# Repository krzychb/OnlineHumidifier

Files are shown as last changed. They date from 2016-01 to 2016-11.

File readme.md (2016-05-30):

# Online Humidifier

This repository provides step by step guide how to automatically control humidity in your home.

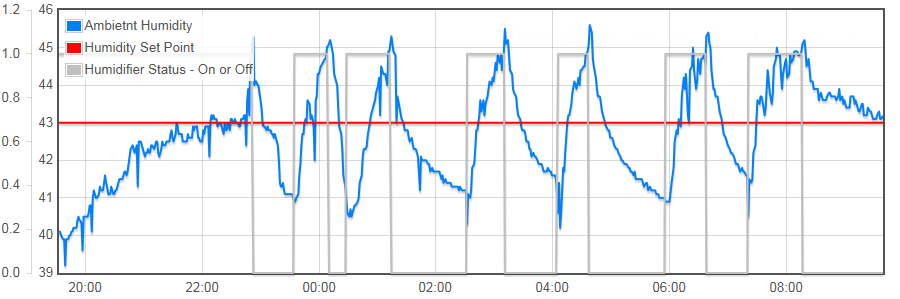
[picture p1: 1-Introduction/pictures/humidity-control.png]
Humidity control in operation


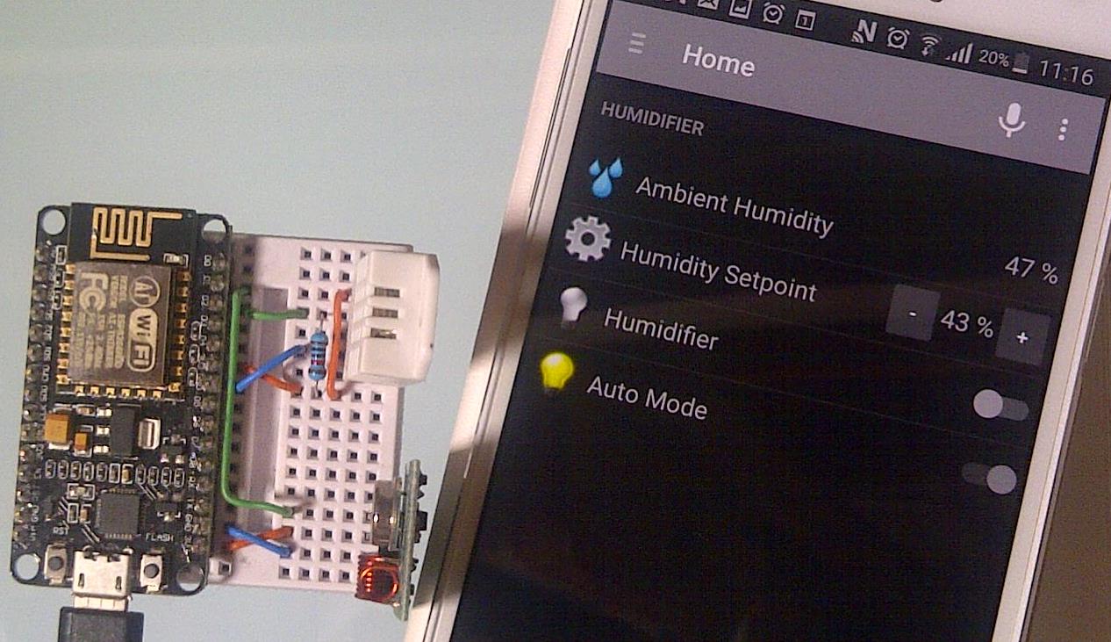
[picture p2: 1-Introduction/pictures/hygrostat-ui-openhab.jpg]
Hygrostat and User interface in openAHB


It is fun to build, consists of easy to get components and costs just $50.

## What You Need

There are only couple of cheap and easy to get components to make your project running

* Humidifier - $25
* ESP8266 board - $8
* Humidity sensor - $5
* RC Socket - $5
* RF Transmitter - $1 
* Breadboard - $5
* Cables - $1
* PC - $0 - you likely have one already as you are reading this web page :smile:

For more details please refer to [Components](2-Components) section.

## Step by Step Tutorial

Depending on your experience, to make implementation easier, this project is broken down into the following steps:

* [**Introduction**](1-Introduction) - check it to learn more about this project and how we are going to implements it.

* [**Components**](2-Components) - describes in detail components you need and what you should look at when buying them.

* [**Setup**](3-Setup) - how to configure Arduino IDE for ESP8266 and compile first sketch

* [**Measure**](4-Measure) - details how to measure humidity with ESP8266 and DHT22 sensor.

* [**Show**](5-Show) - go on line and show humidity measurements in web browser.

* [**Chart**](6-Chart) - how to push data to the cloud and display nice charts with measurements.

* [**Control**](7-Control) - switch on and off wireless RF 433MHz socket using ESP8266 and RF transmitter.

* [**Automate**](8-Automate) - with all preparation done in prevoius steps now we are ready to put our humidity control system together and switch it into auto mode!

* [**Maintain**](9-Maintain) - how to make code uploads easier and quicker with OTA (Over The Air) updates.

#### Appendixes

* [**MQTT**](A1-MQTT) - communicate with other devices using MQTT protocol.

* [**openHAB**](A2-openHAB) - control humidifier from your mobile device using [openHAB](http://www.openhab.org/). 

* [**HTTP**](A3-HTTP) - interface ESP8266 and openHAB using HTTP binding. Is it a viable alternative to MQTT binding?

* [**Persistence**](A4-Persistence) - save sensor values on your local PC instead in the cloud using *persistence* functionality provided by openHAB.

**Note:** If you do not have much experience with Arduino IDE programming and ESP8266, please don't skip ahead in sections of this repository! New concepts are introduced step by step and you may miss something that will be important later. As result you may get stuck trying to make the sketch or other applications work.

## Contribute

Feel free to contribute to the project in any way you like! 

If you find any issues with code or descriptions please report them using *Issues* tab above. 

If you like to discuss it please use [this thread](http://www.esp8266.com/viewtopic.php?p=37446#p37446) on ESP8266 Community Forum. 

## Author

krzychb

## Donations

Invite me to freshly squeezed orange juice.

## Credits

Software for this project has been prepared thanks to great work of the following teams and individuals:
* Arduino team that develops and maintains versatile [Arduino IDE](https://www.arduino.cc/)
* esp8266/Arduino team lead by [Ivan Grokhotkov](https://twitter.com/i_grr) that brought to us great [ESP8266 core for Arduino](https://github.com/esp8266/Arduino)
* [adafruit](https://www.adafruit.com/) providing [DHT sensor library](https://github.com/adafruit/DHT-sensor-library) that is only one of numerous examples of open software adafruit contributed to community
* [Randy Simons](http://randysimons.nl/88,over-mij/) who prepared [433MHz libraries for Arduino](http://randysimons.nl/26-433mhz-libraries-for-arduino)
* [Friends-of-Fritzing](http://friends.fritzing.org/) foundation - developer of widely used and really nice and friendly [Fritzing](http://fritzing.org/home/) 
* [Kamil Baczkowicz]( https://github.com/kamilfb) - the author of versatile and really user friendly [mqtt-spy]( http://kamilfb.github.io/mqtt-spy/), an application that provides tremendous help when testing MQTT communication and debugging MQTT messages
* [Imroy](https://github.com/Imroy) - developer of [PubSubClient](https://github.com/Imroy/pubsubclient), a MQTT library fork of https://github.com/knolleary/pubsubclient

## License

[GNU LESSER GENERAL PUBLIC LICENSE - Version 2.1, February 1999](LICENSE)

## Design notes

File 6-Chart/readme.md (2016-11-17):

# Chart

## Table of Contents

* [Introduction](#introduction)
* [Emoncms](#emoncms)
* [Setup](#setup)
* [Push](#push)
* [Visualize](#visualize)
* [Save](#save)
* [Chart](#chart)
* [Next Steps](#next-steps)

## Introduction

I think that development of applications for ESP8266 has been made really easy to everybody. This is thanks to [ESP8266 core for Arduino](https://github.com/esp8266/Arduino) developed by [Ivan Grokhotkov](https://twitter.com/i_grr) and [esp8266/Arduino](https://github.com/esp8266/Arduino/graphs/contributors) team. In [previous section](../5-Show) I have shown how easy it is to present measurements online with just couple of simple modifications to existing example sketch.

In this section I would like to make another step - push data to the cloud and present them online on a chart. 

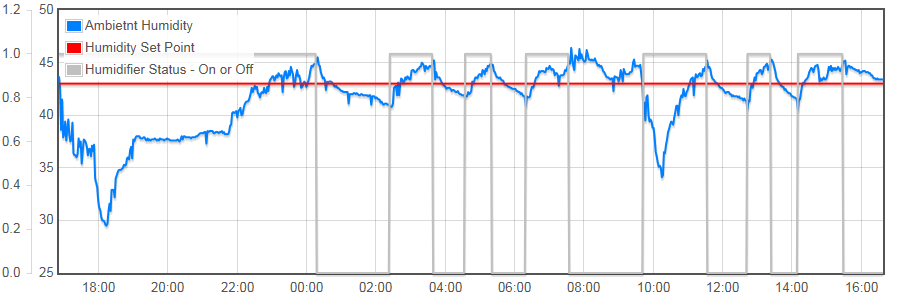
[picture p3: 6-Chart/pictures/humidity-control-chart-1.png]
A sample humidity control chart


## Emoncms

There are several cloud services that you can use for such purpose. I am pretty familiar with [ThingSpeak](https://thingspeak.com/) and [Emoncms](http://emoncms.org/) and will refer to them.

For this particular project I propose to use [Emoncms](http://emoncms.org/). I found it easier to configure a chart to show multiple values, that you can quickly browse or zoom for the period you want. 

After putting our automatic humidity control into operation we would like to be able to analyse its performance. We will do it by checking relationship between humidity set point, actual humidity value and on/off status of humidifier. It is easier to do it on a single chart rather than on three separate charts. 

On the other hand I can recommend [ThingSpeak](https://thingspeak.com/) if you need flexibility of extra data processing before displaying. ThinkSpeeak provides MATLAB for that and imagine what fancy things you can do with it! After processing you can then display the data using huge [charts or plots](https://www.mathworks.com/products/matlab/plot-gallery.html?refresh=true) gallery.

## Setup

Go ahead, open http://emoncms.org/ and register. All you need to provide is login, e-mail and password. Once registered, you will get free access to storage space for your data as well as dashboards to present them online.

To learn how to send data to Emoncms, login into it, go to *Setup > Inputs* and open [Input API Help](http://emoncms.org/input/api) link. Under chapter *Available JSON commands* you will be able see a link like: ``` http://emoncms.org/input/post.json?json={power:200}&apikey=9a3e3c9cf65c70a597097b065dcb24e3 ```. This is so called [JSON](https://en.wikipedia.org/wiki/JSON) command used to send data to Emoncms cloud. It consists of three parts:

1.	``` http://emoncms.org/input/post.json?json= ``` : an url to server that processes JSON,
2.	``` {power:200} ``` : data to be sent as a name:value pair (you can add more pairs separated by comma),
3.	``` apikey=9a3e3c9cf65c70a597097b065dcb24e3 ``` : unique identifier of your space on Emoncms.

You will find your API keys at the top of API Hep page. To post data use “Read & Write” key.

**Note:** Formal description of JSON is provided in [RFC 7159](https://tools.ietf.org/html/rfc7159) standard. According to this standard, the name (as a string) should begin and end with quotation marks. This is not the case in example above, as `power` is not enclosed in quotation marks. Keep in mind, that even if it works for Emoncms, it may not work elsewhere. 

## Push

Now we need to instruct ESP to periodically measure humidity and open similar JSON link but containing something like ``` {Humidity:43.5} ```, where ``` Humidity ``` is the name of value we are sending and ``` 43.5 ``` is the value itself. 

Let us program the above operations as functions so it is easier to follow what our code is doing. Functions will be called in a loop every 20 seconds, or so that we can quickly see results. We can increase this period once testing is complete – afterwards is not really required to check humidity level in a room every 20 seconds.

```cpp
loop()
{
  measureHumidity();
  sendDataToEmoncms();

   delay(20000);  // wait 20 seconds
}
```

To prepare the function that will measure humidity, open [DHTtester.ino sketch we have discussed before](../4-Measure#software-setup), copy code and modify it, so humidity is measured and stored in a global variable ``` humidity ```. What I did looks like follows:

```cpp
void measureHumidity(void)
{
  humidity = dht.readHumidity();
  if (isnan(humidity))
  {
    Serial.println("Failed to read from DHT sensor!");
    return;
  }
  Serial.print("Humidity: ");
  Serial.println(humidity);
}
```

You will also need a function to send JSON command to Emoncms and it looks like below.

```cpp
void sendDataToEmoncms(void)
{
  if (client.connect(emoncmsServer, 80))
  {
    String getJSON = "";
    getJSON += "GET http://" + (String) emoncmsServer;
    getJSON += "/input/post.json?json={Humidity:" + (String) humidity + "}";
    getJSON += "&apikey=" + apiKeyEmoncms + "\n";
    getJSON += "Connection: close\n\n";
    client.print(getJSON);
    // display response from Emoncms
    while (client.available())
    {
      Serial.write(client.read());
    }
    Serial.println("Data sent to Emoncms");
  }
  else
  {
    Serial.println("Connection to Emoncms failed");
  }
  client.stop();
}
```

This code opens a new client connection to Emoncms server, sends JSON command, shows received response and finally closes the connection. 

To make this code work we need to declare global variable ``` humidity```.

```cpp
float humidity;
```

We should also declare a string ```emoncmsServer``` containing domain name of Emoncms, another string with the API key (enter your own!) and declare ``` client ``` object. 

```cpp
// Domain name of emoncms server - "emoncms.org"
// If unable to connect with domant name, use IP adress instead - "80.243.190.58"
const char* emoncmsServer = "emoncms.org";
// enter your Write & Write API Key below 
String apiKeyEmoncms = "9a3e3c9cf65c70a597097b065dcb24e3";
WiFiClient client;
```

A copy of complete sketch is saved as [OnlineHumidifier-Graph](OnlineHumidifier-Graph/) and consists of three files that contain individual parts of code – initialization, ``` setup() ``` & ``` loop() ```, humidity measurement and sending data to Emoncms. Such code “modularity” will make it easier to follow and understand growing code as we will be adding some more new functionality.

## Visualize

Once you upload and run this sketch, go to [Inputs](http://emoncms.org/input/view) where you should be able to see humidity value periodically send on Emoncms.

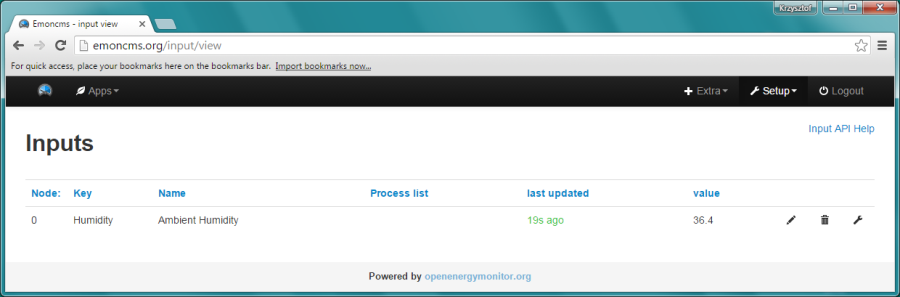
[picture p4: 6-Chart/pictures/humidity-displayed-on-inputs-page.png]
Humidity value displayed on Inputs page


In case of issues check on Serial Monitor what messages are shown – especially what is the reply from Emoncms after JSON command is sent. If command is properly formatted and includes a valid API key, the reply will be just ``` ok ```. Otherwise you should see specific error codes. A handy way to you can troubleshoot is to prepare JSON command in text editor, paste it to a web browser and check what reply is returned. 

If JSON string is correctly formatted, then you should see response as below:

JSON string phrased correctly

In case of errors, for instance if API key is incorrect, you should see specific message:

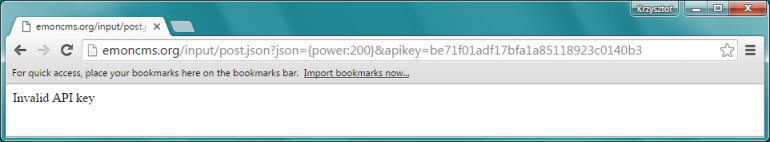
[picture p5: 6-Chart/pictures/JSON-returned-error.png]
JSON string returned an error


Before going to the next step you need make this sketch working, so humidity is properly updated under [Inputs](http://emoncms.org/input/view) every 20 seconds, or according to other specific delay defined in the ``` loop()```. [Minimum interval you can post data to Emoncms is 10s](http://emoncms.org/site/usage) so put a brake on your ESP8266 module!

## Save

In next steps we need to instruct Emoncms to save all the values we send. What you see under [Inputs](http://emoncms.org/input/view) is just last received value. Track record of inputs in maintained under [Feeds](http://emoncms.org/feed/list). To add the Humidity input Feeds, click the wrench symbol shown on right.

Then select Feed engine and press *Add* button

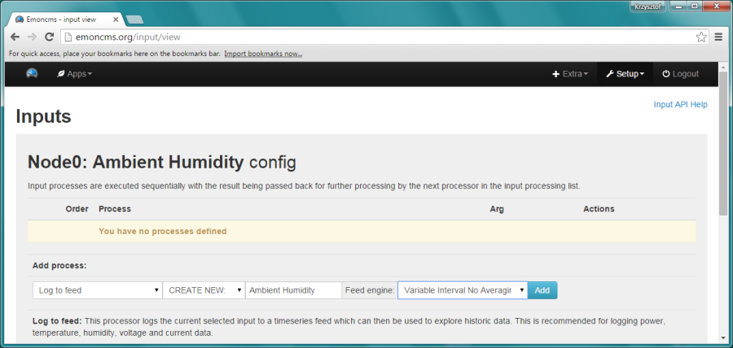
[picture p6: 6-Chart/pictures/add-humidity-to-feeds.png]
Adding Humidity input to Feeds


Congratulations! Now all humidity values you send are stored on Emoncms.

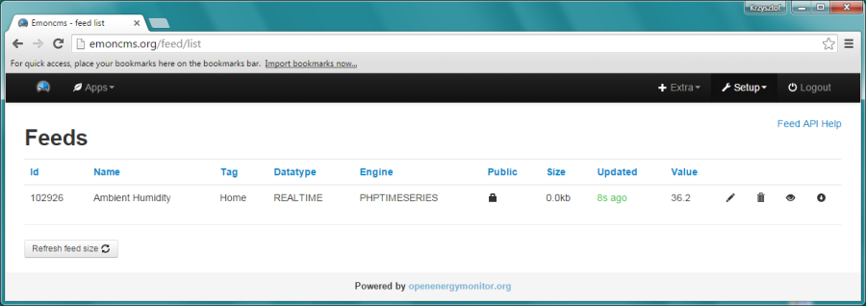
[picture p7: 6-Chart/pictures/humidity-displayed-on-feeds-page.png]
Humidity value displayed on Feeds page


## Chart

We are almost there! We can now use humidity feed to show in on a chart. Go to [Dashboards](http://emoncms.org/dashboard/list), click *New* and then click edit symbol on newly created dashboard. 

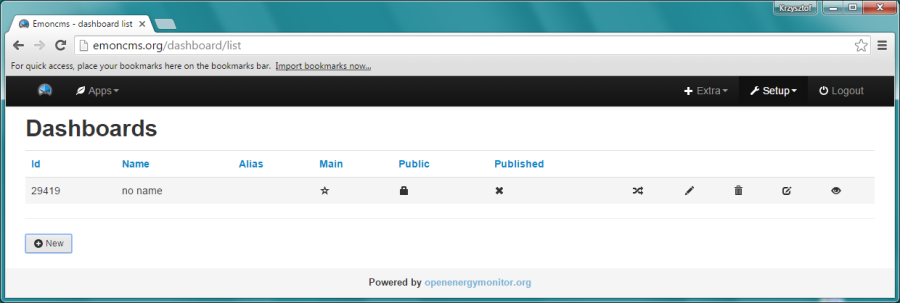
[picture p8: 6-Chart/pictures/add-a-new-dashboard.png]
Add a new dashboard


Open *Visualisation* drop down list, select *rawdata*, click and place a rectangle representing the new chart. After that click *Configure* and select recently created feed with humidity values. After saving changes you should be able to see the chart with humidity measurement updated online with values sent from your ESP board.

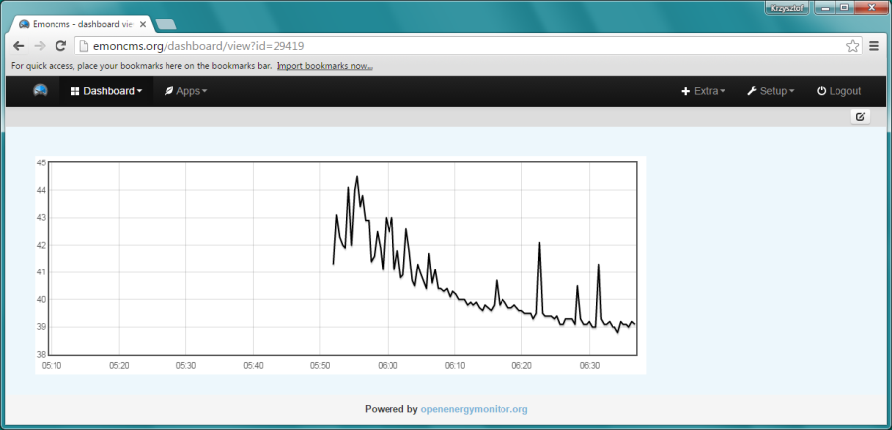
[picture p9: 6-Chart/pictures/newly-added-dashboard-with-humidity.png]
Newly added dashboard with humidity chart


Go ahead and experiment with various visualizations, widgets, containers and text. For more details how to use them, refer to https://github.com/emoncms/emoncms.

## Next Steps

Once you get comfortable with your new sketch and Emoncms, make some improvements by sending more than just a single name:value pair at a time. For example an instruction like ```{Humidity:43.5, Temperature:22.3}```  will send to Emoncms two variables, first named ``` Humidity ``` with value  of ``` 43.5 ``` and second named ``` Temperature ``` with value of ``` 22.3 ```. Then practice putting both variables on a single chart. To do so use *multigraph* type chart from *Visualizations*.

This concludes my instructions how to send data to Emoncms and show them on a chart. In next section [Control](../7-Control) I will show you how to switch humidifier on and off remotely. With this functionality in place we will be just a step ahead from getting our humidifier automatically controlling humidity! 

Stick with me – this will be fun!

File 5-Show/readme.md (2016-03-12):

# Show

## Table of Contents

* [Introduction](#introduction)
* [What You Need](#what-you-need)
* [Setup Web Server](#setup-web-server)
* [Test It](#test-it)
* [Next Step](#next-step)

## Introduction

In [previous section](../4-Measure)  I have shown how to use an inexpensive digital humidity sensor DHT22 with ESP8266 to measure relative humidity. We have been displaying humidity values in Serial Monitor of Arduino IDE.

Now it is time to do next step and use ESP’s Wi-Fi functionality and show humidity values in a web browser. I am really excited to show you that, since it provides freedom to get our measurements online and shown them to the whole world!

Such functionality is also fairly easy to complete. There is an example sketch available in Arduino IDE that demonstrates how to set up a simple web server on an ESP. We will use it to serve a web page with humidity measurement that we or anybody else can open in a web browser :sunglasses:

Let's get started!

## What You Need

To implement this part of project you will need the following:

* All the hardware used in [previous section](../4-Measure) to program ESP and to measure humidity:
  * PC with [esp8266/Arduino](https://github.com/esp8266/Arduino) IDE
  * ESP module
  * DHT22 sensor on breadboard
* Wi-Fi access for PC and ESP module to the same network

## Setup Web Server

Start by going to File > Examples > ESP8266WebServer and opening HelloServer.ino sketch.

Update station ID and password in sketch so your ESP can access Wi-Fi network and upload it.

Once upload is complete press Ctrl+Shift+ M to open Serial Monitor. What you are looking for is a message like on screenshot below, that ESP module has connected to Wi-Fi network and IP address of web server running on ESP.

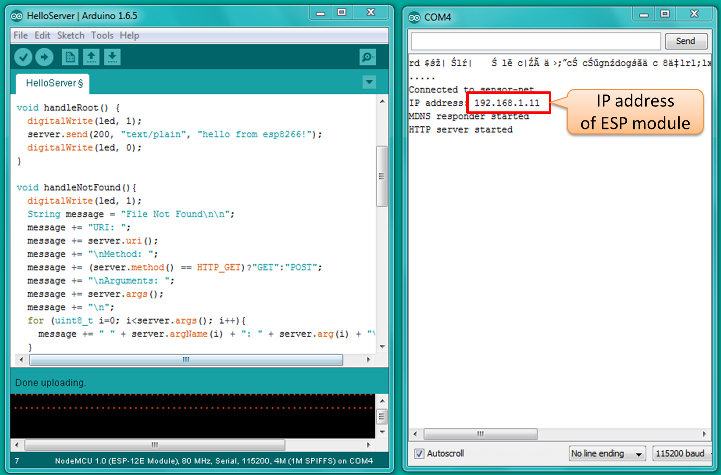
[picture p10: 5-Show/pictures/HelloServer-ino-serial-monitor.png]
IP address of ESP module connected to Wi-Fi network


Go ahead, open web browser and type IP address provided on Serial Monitor. If you are connected to the same network you should be able to see “hello from esp8266!” message from ESP module. 

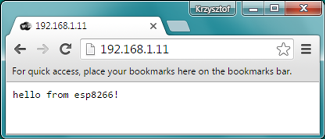
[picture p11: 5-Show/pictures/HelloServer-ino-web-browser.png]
"hello from esp8266!” in web browser


Now go to the sketch and locate function that sends out the “hello” message. What we would like to do, is to change this message, so it contains current humidity value. We will reuse code we tested so far. First please open File > Examples > ESP8266WebServer > HelloServer.ino sketch and save it as OnlineHumidifier-Show.ino. Then open File > Examples > DHT sensor library > DHTtester.ino sketch and copy from it the code we need to print out humidity value. Please see below pieces of code we need.

Declaration section
```cpp
#include "DHT.h"
DHT dht(D2, DHT22);
```

Updated ``` handleRoot() ``` function

```cpp
void handleRoot() {
  digitalWrite(led, LOW);
  String message = "hello from esp8266!\n";
  message += "Humidity = ";
  message += (String) dht.readHumidity();
  message += "%\n\n";
  server.send(200, "text/plain", message);
  digitalWrite(led, HIGH);
}
```

In ``` setup() ``` function

```cpp
dht.begin();
```

To follow exactly how the code was modified please check [OnlineHumidifier-Show.ino]( OnlineHumidifier-Show/OnlineHumidifier-Show.ino) sketch in this repository. 

## Test It

After uploading updated sketch we will be able to see current humidity value each time we open IP address of our ESP in a web browser.

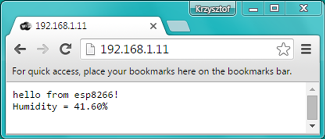
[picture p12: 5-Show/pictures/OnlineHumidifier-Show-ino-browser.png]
Humidity value in web browser


## Next Step

Now you know to use ESP8266 to display current humidity measurement value in a web browser. In section [Chart](../6-Chart) I will show you how to publish individual measurements to a cloud and display them over time on an on-line chart.

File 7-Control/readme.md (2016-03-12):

# Control

## Table of Contents

* [Introduction](#introduction)
* [Select RF Socket](#select-rf-socket)
* [Install Library](#install-library)
* [Connect Components](#connect-components)
* [Prepare the Sketch](#prepare-the-sketch)
* [Configure the Transmitter](#configure-the-transmitter)
* [Operate the Socket](#operate-the-socket)
* [Troubleshooting](#troubleshooting)
* [Operate the Socket from Web Browser](#operate-the-socket-from-web-browser)
* [The Next Step - Put it All Together](#the-next-step---put-it-all-together)

## Introduction

In [previous section](../6-Chart) I have presented how to show your measurements online using Emoncms.org that is powerful web application for logging and visualizing data. We need such data for analysis of performance of our humidity control system. We do not have this system operating yet, but we are just there. In this section I would find a demonstrate how to control our humidifier, so we can then remotely switch it on and off depending on current humidity value. 

To do so you will need the following hardware used in section [Measure](../4-Measure/) and in addition:

* RF433 transmitter
* RF433 socket

## Select RF Socket

We should start off by finding proper library to control RF433 socket. There is variety of such sockets on the market as well as variety of Arduino libraries to control them. I propose you to start with nice wiki site with [433MHz libraries for Arduino](https://bitbucket.org/fuzzillogic/433mhzforarduino) by [Randy Simons](http://randysimons.nl/88,over-mij/). It provides couple of libraries for 433 MHz devices including mains sockets. The library I found on this site works perfectly with my ORNO socket. It may or may not work for specific socket you have. Therefore before buying particular socket do research on internet if there is a library available for to control it. You may also decipher protocol used for particular socket and this is a subject by its own. Please see below couple of links to give you an idea what you should be looking for: 

* [Decoding and sending 433MHz RF codes with Arduino and rc-switch](http://www.wes.id.au/2013/07/decoding-and-sending-433mhz-rf-codes-with-arduino-and-rc-switch/)
* [Arduino radio remote control RF 433MHz/315MHz](http://jubitoblog.blogspot.com/2014/06/arduino-radio-remote-control-rf.html)
* [433 MHz system for your Arduino](https://arduinodiy.wordpress.com/2014/08/12/433-mhz-system-for-your-arduino/)
* [433 MHz driver specific thread on ESP8266 Forum](http://www.esp8266.com/viewtopic.php?p=14704#p14704)

## Install Library

Once you have the library you need to install it. Let us do it for library I am using. First I need to download library from https://bitbucket.org/fuzzillogic/433mhzforarduino/wiki/Home. It is provided in section Downloads as a zip file. The all I need to unzip RemoteSwitch library folder and copy it to the folder with other Arduino libraries. You can locate it in Arduino IDE under *File > Preferences > Sketchbook location*. In my case the path to final location is as follows: *C:\Users\Krzysztof\Documents\Arduino\libraries*. For systematic guide how to install libraries please refer to http://www.arduino.cc/en/Guide/Libraries.

## Connect Components

Before switching humidifier control into auto mode let us do some basic testing how RemoteSwitch library works with [RF433 ORNO socket](../2-Components#humidifier-and-rc-socket).

To begin with we need to hook up RF433 transmitter to ESP8266 module. The transmitter has just three pins:

1.	ATAD : transmission modulation
2.	VCC : DC power supply (3 - 12V)
3.	GND : ground

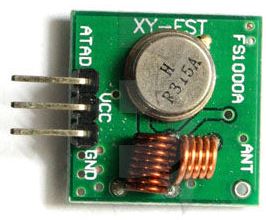
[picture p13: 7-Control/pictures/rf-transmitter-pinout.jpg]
RF Transmitter


Please see below connection diagram. Transmission modulation is done using D1 digital I/O pin. You may select any other available I/O pin. As for power supply I am using 3.3V available on-board. If you have NodeMCU 1.0 LoLin, you can use 5V instead to provide stronger RF signal and better range. 5V is broken out on this board as *VV* under pin that on other NodeMCU 1.0 boards (like Amica) is marked as *RSV*.

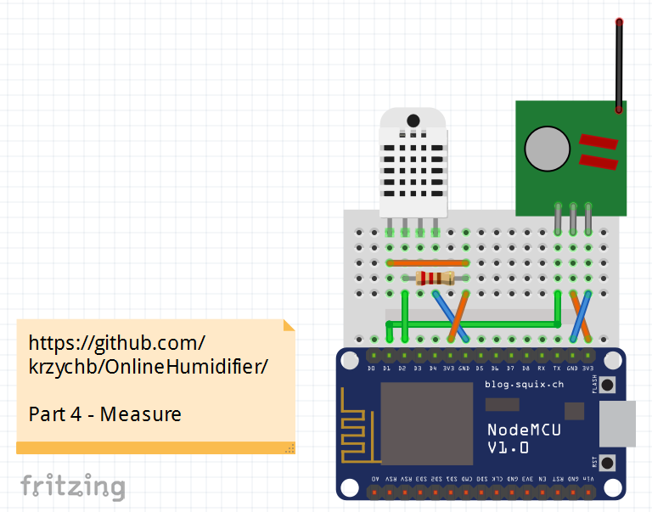
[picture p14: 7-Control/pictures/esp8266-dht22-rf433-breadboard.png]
Breadboard connection schematic of RF433 transmitter and DHT22 to ESP8266

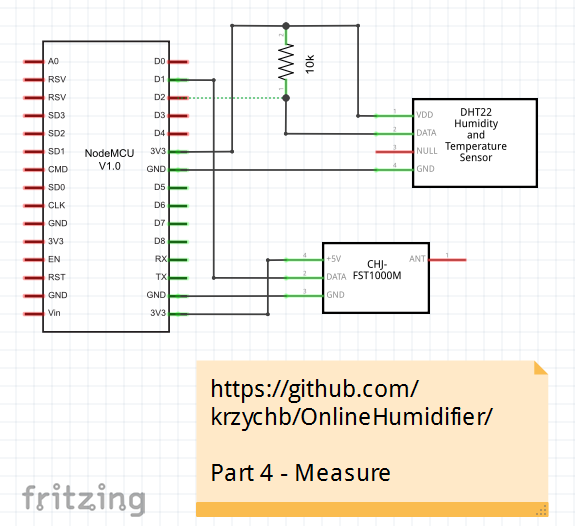
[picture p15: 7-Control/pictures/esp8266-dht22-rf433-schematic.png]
Connection schematic of RF433 transmitter and DHT22 to ESP8266


## Prepare the Sketch

Now we need a sketch to operate RF 433 transmitter (modulate RF transmission) in a protocol recognized by RF 433 socket as a command to switch it on or off. This is provided by *RemoteTransmitter* library. See the sketch below. What it does is just toggling the socket on and off every 1 second. 

```cpp
#include <RemoteTransmitter.h>
#define RF433_TR_PIN D1   // pin where RF433 Transmitter is connected to
ActionTransmitter actionTransmitter(RF433_TR_PIN);

void setup()
{
  Serial.begin(115200);
  Serial.println();
  Serial.println("RF433-SocketTester.ino");
}

bool outputRF;

void loop()
{
  // invert (negate) current state of outputRF variable
  outputRF = !outputRF;

  actionTransmitter.sendSignal(1, 'A', outputRF);
  
  delay(1000);
}
```

## Configure the Transmitter

The key command to operate socket is ``` actionTransmitter.sendSignal(1, 'A', outputRF) ``` and it has the following three parameters:

1.	*systemCode* : 5-bit address (dip switches in remote). Range ``` [0..31] ```
2.	*device* :	Device to switch. Range: ``` [A..E] ``` (case sensitive!)
3.	*on* : ``` True ```, to switch on. ``` False ``` to switch off

Selection of *systemCode* and *device* for ORNO socket is done using dip switches. Please see picture below of setting the *systemCode = 1* on remote control and both *systemCode = 1*  as well as *device = A* on the socket.

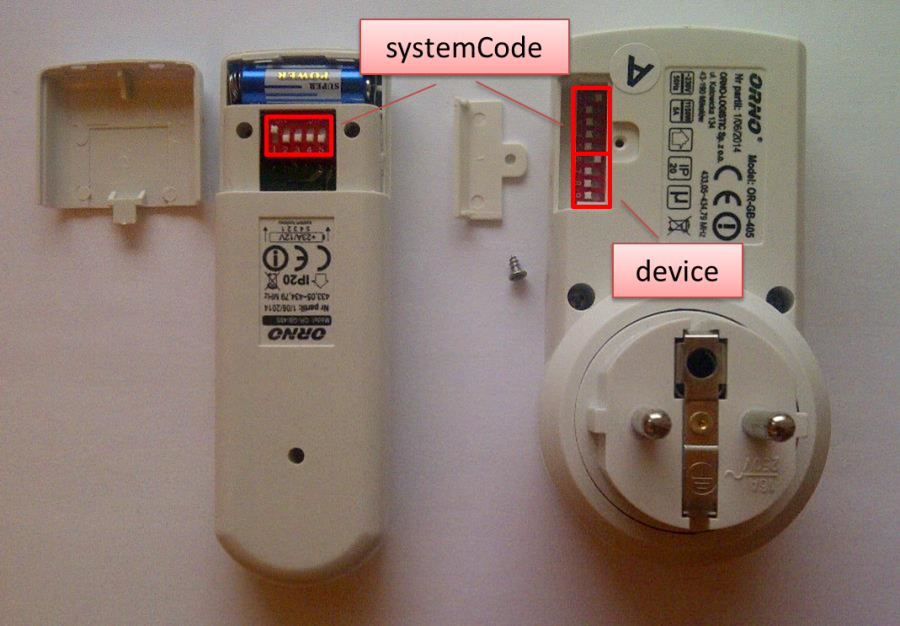
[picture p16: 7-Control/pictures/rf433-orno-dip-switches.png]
Example of DIP switch settings on RF433 remote control and socket


## Operate the Socket

Go ahead, connect all components, load the sketch and make it working.

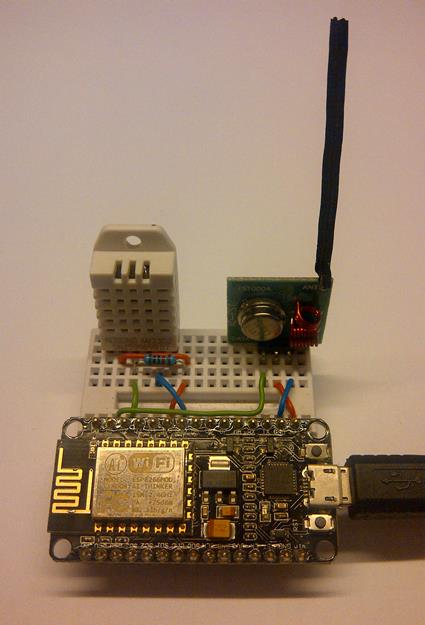
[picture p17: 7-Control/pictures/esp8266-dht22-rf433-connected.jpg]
RF433 transmitter and DHT22 connected to ESP8266


Currently I am using RD 433 transmitter without the antenna (the black cable connected to the ANT terminal shown on picture above). This is because I found it operating without any problems though walls on distance of couple of meters and that was more than enough in my case.

You can use sketch [RF433-SocketTester.ino](RF433-SocketTester/RF433-SocketTester.ino) to verify how it performs in your case by moving transmitter away from your socket until the relay in socket stops clicking. Add the antenna of about 17.28 cm / 6.80 inch, if you need to operate it close to the maximum range.  Check [this post](http://blog.solidremote.com/post/rf-module-external-antenna-design.aspx) for antenna recommendations.

## Troubleshooting

In case of issues use remote control for troubleshooting. It is normally provided together with sockets.

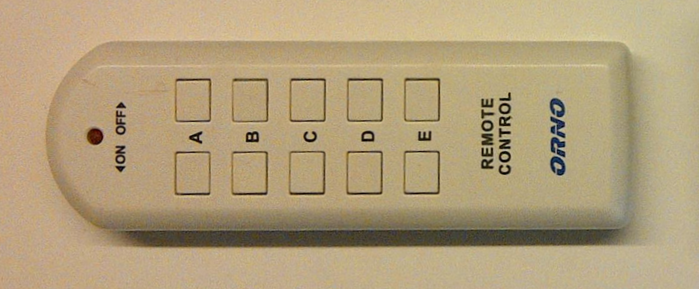
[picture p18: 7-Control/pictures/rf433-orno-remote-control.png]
RF 433 MHz remote control by ORNO


Verify that the *systemCode* on remote is set up exactly the same as on the socket. Then use the On / Off buttons that correspond with one of *devices* A through E that has been selected using DIP switch on your socket. If your remote control have different method of pairing with socket then you may need to search for a different library. 

There are plenty of models of RF433 sockets on the market. You may not be lucky finding a ready library to operate your RF433 socket. If this is the case, resort to sniffing the protocol used by remote to decipher command for putting the socket on and off. This a subject by its own. To have an idea what is required and how to approach this task, check [this article](https://arduinodiy.wordpress.com/2014/08/12/433-mhz-system-for-your-arduino/).

In any case make sure that your socket is operational from the sketch before going to the next step.

## Operate the Socket from Web Browser

It is time to start joining the dots and putting together some pieces of software and hardware we have developed so far. Let us combine the code to operate socket we have just tested with [code developed previously for a web browser](link). This is to prepare a sketch to switch the socket on and off from the browser.

To start with open previously used sketch [OnlineHumidifier-Show](link) and save it as *OnlineHumidifier-Control*.  The idea is to update this sketch with two links, that when clicked, will be processed by ESP and turn on or off the humidifier connected to the RF422 socket.

I propose the following simple format of links (let us assume that ``` 192.168.1.120 ``` is IP of your ESP):

* ``` http://192.168.1.120/humidifier/1 ``` - to turn humidifier on
* ``` http://192.168.1.120/humidifier/0 ``` - to turn it off

Now we need to write a procedure that will recognize request for ``` /humidifier/1 ```, and issue the command to switch the socket on (or off for ``` /humidifier/0 ```). It turns out that there is already some code in the sketch you have just saved, that can be used for this purpose. Go to ``` setup() ``` and Look for the following code:

```cpp
server.on("/inline", [](){
  server.send(200, "text/plain", "this works as well");
});
```

Now load this sketch, enter IP address of ESP shown in Serial Monitor and add ``` /inline ``` at the end (if IP of you ESP is ``` 192.168.1.120 ```, then the whole url will look like ``` http://192.168.1.120/inline ```). Once entered you should see the following output.

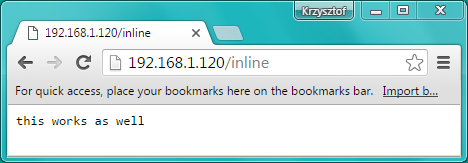
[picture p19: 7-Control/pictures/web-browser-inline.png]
Another address and output in web browser


Basing on this example we should be able to add similar code that will run if the link is in format that we need, i.e. ``` http://192.168.1.120/humidifier/1 ``` (or ``` /0 ```). Let us do it:

```cpp
server.on("/humidifier/1", [](){
  actionTransmitter.sendSignal(1, 'A', True);
  server.send(200, "text/plain", "Humidifier switched On");
});

server.on("/humidifier/0", [](){
  actionTransmitter.sendSignal(1, 'A', False);
  server.send(200, "text/plain", "Humidifier switched Off");
});
```
After opening updated code in web browser, the following will be displayed:

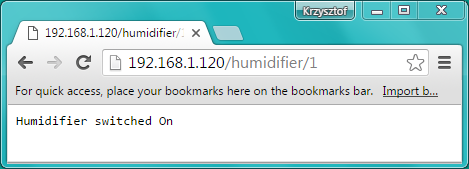
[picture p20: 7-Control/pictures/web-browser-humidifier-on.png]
Message in web browser - Humidifier switched On

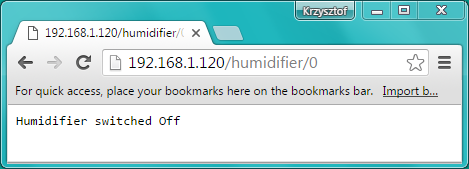
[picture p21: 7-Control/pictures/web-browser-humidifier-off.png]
Message in web browser - Humidifier switched Off


This is fantastic! We can control humidifier from web browser :+1:

Using the code we have just tested together with [OnlineHumidifier-Show](../5-Show/OnlineHumidifier-Show/) and [OnlineHumidifier-Chart](../6-Chart/OnlineHumidifier-Chart/) sketches developed previously, we are now in position to provide a link for switching humidifier on and off as well as displaying ambient humidity on a single web page. This time, instead of providing a page in a plan text, we will use HTML for easier formatting. For convenience I will prepare a separate procedure to do that:

```cpp
void showControlScreen(void){
  String message;
  message += "<html>";
  message += "<head><meta http-equiv='refresh' content='5'/><title>Online Humidifier</title></head>";
  message += "<body>";
  message += "<h3>Humidifier Control</h3>";
  message += "<p>";
  message += "Humidity : " + (String) humidity + "%<br />";
  message += "Humidifier : " + (String) humidifier + "<br />";
  message += "Operate : ";
  message += "<a href=\"/humidifier/1\">On</a>";
  message += " / ";
  message += "<a href=\"/humidifier/0\">Off</a>";
  message += "</body>";
  message += "</html>";

  server.send(200, "text/html", message);
}
```

This procedure is using global variables that contain ambient humidity and humidifier status. The statement ``` 'refresh' content='5' ``` will cause the page to reload itself every 5 seconds, so we can see humidity value changes. 

The  HTML code to render a link looks as follows ``` <a href="/humidifier/1">On</a> ```. Corresponding statement in Arduino code should contain additional escape character ``` \ ``` before each quotation mark like this -``` \" ```. This is to distinguish it from quotation mark that means beginning or end of a string.

Complete sketch is saved as [OnlineHumidifier-Control](OnlineHumidifier-Control/). If you compile it, upload and open ``` http://192.168.1.120/humidifier/0 ``` (do not forget to replace ``` 192.168.1.120 ``` with IP of your ESP!) the following will be displayed in web browser:

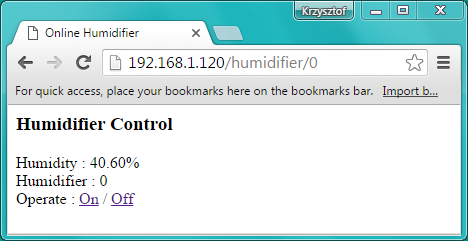
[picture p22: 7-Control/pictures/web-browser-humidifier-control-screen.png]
Humidifier control screen


I encourage you to improve this sketch by changing the font, adding graphics, alter colors of displayed information basing on humidifier status or humidity range, show % of the time when humidifier was on, etc.

## The Next Step - Put it All Together

Now we have all key pieces of the code to control our humidifier remotely and see how it influences ambient humidity. In next section [Automate](../8-Automate) I would like to show how to make it work autonomously and adjust ambient humidity to a set point we define.  Do not miss to check it and implement to work for you!

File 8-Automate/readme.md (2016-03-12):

# Automate

## Table of Contents

* [Introduction](#introduction)
* [The Hysteresis Controller](#the-hysteresis-controller)
* [What Else?](#what-else)
* [Let's Get it Work](#lets-get-it-work)
* [Auto Mode On](#auto-mode-on)
* [How does it Perform?](#how-does-it-perform)
* [Next Step](#next-step)

## Introduction

Now comes the fun part of joining all the dots we have been discussing and testing in last seven [sections](https://github.com/krzychb/OnlineHumidifier#step-by-step-tutorial). All we need to do now is to write a simple procedure that will compare ambient humidity against set point and switch humidifier on if it is below or on if it is above the set point.

Before you rush to write this procedure think about humidifier being constantly switched on and off for any swing of humidity. To avoid such situation, it is a common practice to add a dead band below and above the set point and do not operate humidifier if ambient humidity is within the dead band. Exactly the same method of control is used in electric iron or in toilet flush. 

The dead band range above and below the set point is called hysteresis. An automatic controller that is working as desribed above is called [bang–bang controler](https://en.wikipedia.org/wiki/Bang%E2%80%93bang_control) or hysteresis controller.

## The Hysteresis Controller

You can experiment what will happen if you have no hysteresis or if you set it to specific value. At this stage, as a starting point, let us assume a hysteresis of +/- 2% RH.  Below is a procedure that implements hysteresis controller:

```cpp
void executeHumidityControl(void)
{
  Serial.print("Ambient humidity : ");
  Serial.print(humidity, 1);
  Serial.print("%, set point : ");
  Serial.print(humiditySetPoint, 1);
  Serial.print("%, humidifier : ");
  if (humidity > humiditySetPoint + 2)
  {
    // ambient humidity is above the set point
    // action : switch humidifier Off
    humidifier = LOW;
  }
  else if (humidity < humiditySetPoint - 2)
  {
    // ambient humidity is below the set point
    // action : switch humidifier On
    humidifier = HIGH;
  }
  else
  {
    // ambient humidity is within +/- 2% hysteresis
    // therefore do not alter current status of humidifier
    Serial.print("(No Change) ");
  }
  Serial.println(humidifier == HIGH ? "On" : "Off");

  //
  // Operate humidifier connected to RF socket
  //
  actionTransmitter.sendSignal(1, 'A', humidifier);
}
```

## What Else?

We will finally put into operation the last piece of hardware described under [Components](../2-Components), that has not been used so far – the humidifier.  It will act as the final element  of our [control system](https://en.wikipedia.org/wiki/Control_system).

Besides that you will need all the other components used and tested previously.

Speaking in terms of [control system](https://en.wikipedia.org/wiki/Control_system), they will act as controller (ESP8266 running the sketch), the input sensor (DHT22) and the output actuator (RF transmitter together with RF socket).

As the [HMI - Human Machine Interface](https://en.wikipedia.org/wiki/User_interface) we will use a web browser on a PC.

## Let's Get it Work

To start with, open previously prepared [OnlineHumidifier-Control](../7-Control/OnlineHumidifier-Control/) sketch and save it as *OnlineHumidifier-Automate.ino*. Then copy the above code of [hysteresis controller](#the-hysteresis-controller) and add it to the sketch as a separate*Control.ino* file.

To analyse how controller is performing we need to plot humidity values on a chart. We are already familiar how to do it and have the code ready. Copy the file [Emoncms.ino](../6-Chart/OnlineHumidifier-Chart) and add it to the folder with *OnlineHumidifier-Automate.ino* sketch.

Now we need to update *OnlineHumidifier-Automate.ino* sketch so all these files work together. 

To switch controller to auto mode please add handling of additional link as follows:

```cpp
  server.on("/humidifier/Auto", []() {
    autoMode = true;
    showControlScreen();
  });
```

In next step update ``` showControlScreen() ``` procedure to show additional information (controller mode, humidity set point and the new *Auto* link:

```cpp
void showControlScreen(void) {
  String message;
  message += "<html>";
  message += "<head><meta http-equiv='refresh' content='20'/><title>Online Humidifier</title></head>";
  message += "<body>";
  message += "<h3>Humidifier Control - ";
  message += (String) (autoMode == true ? "Auto" : "Manual");
  message += "</h3>";
  message += "<p>";
  message += "Humidity : " + (String) humidity + "%<br />";
  message += "Humidifier : " + (String) humidifier + "<br />";
  message += "Operate : ";
  message += "<a href=\"/humidifier/1\">On</a>";
  message += " / ";
  message += "<a href=\"/humidifier/0\">Off</a>";
  message += " / ";
  message += "<a href=\"/humidifier/Auto\">Auto</a>";
  message += "</body>";
  message += "</html>";

  server.send(200, "text/html", message);
}
```

You will also need to update the ``` loop() ``` to periodically measure humidity, execute control once it is put into auto mode and send data to Emoncms.org:

```cpp
void loop(void)
{
  server.handleClient();

  if (millis() % 20000 == 0)
  {
    measureHumidity();
    if (autoMode == true)
    {
      executeHumidityControl();
    }
    sendDataToEmoncms();
  }
}
```

Plese note we have reduced period of measurement to 20 seconds. This is done with ``` if (millis() % 20000 == 0) ``` statement.

The last setep is to update procedure ``` sendDataToEmoncms() ``` so it sends to Emoncms.org three additional values: humidity set point, status of humidifier (on or off) and information if controller is in auto or manual mode.

```cpp
void sendDataToEmoncms(void)
{
  if (client.connect(emoncmsServer, 80))
  {
    String getJSON = "";
    getJSON += "GET http://" + (String) emoncmsServer;
    getJSON += "/input/post.json?json={";
    getJSON += "Humidity:" + (String) humidity + ",";
    getJSON += "HumiditySP:" + (String) humiditySetPoint + ",";
    getJSON += "Humidifier:" + (String) humidifier + ",";
    getJSON += "AutoMode:" + (String) autoMode;
    getJSON += "}&apikey=" + apiKeyEmoncms + "\n";
    getJSON += "Connection: close\n\n";
    client.print(getJSON);
    (...)

}
```

You will need to do some additional minor updates like declaration and initialization of new variables and switching the auto mode off if you decide to operate the humidifier manually. For details please refer to complete code in [OnlineHumidifier-Automate](OnlineHumidifier-Automate) folder.

## Auto Mode On

Go ahead compile, upload and debug your sketch. Once done, after opening ``` http://IP-of-your-ESP/humidifier/Auto ``` link in web browser you should be able to see a screen as below:

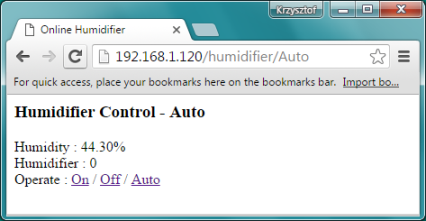
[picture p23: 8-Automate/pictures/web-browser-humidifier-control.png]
Humidifier control screen in a web browser


# How does it Perform?

Once sketch is running and ESP is sending data to Emoncms.org, you will soon see new entries under [Inputs](http://emoncms.org/input/view).

Update configuration of collected data as discussed in section [Chart]( ../6-Chart).

Add missing description in column Name under [Inputs](http://emoncms.org/input/view). Such description will then show up in [Feeds](http://emoncms.org/feed/list) and on *MultiGraph* charts and it helps during data analysis.

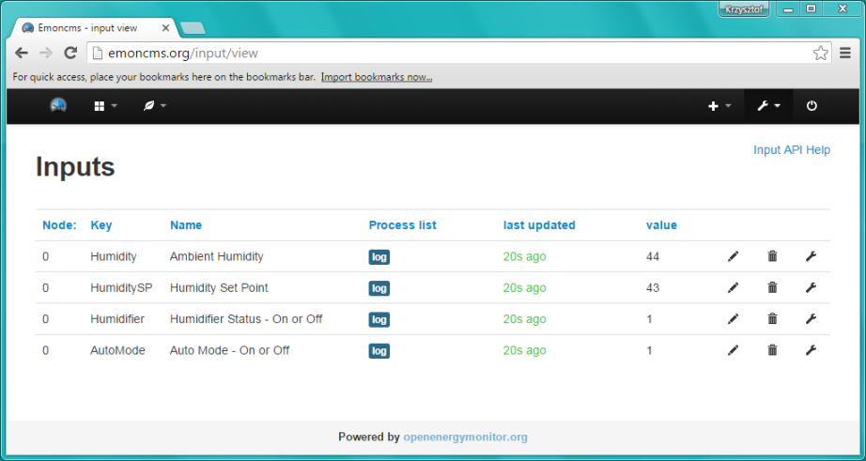
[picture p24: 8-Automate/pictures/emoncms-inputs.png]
Updated Inputs on Emoncms.org


Add [Inputs](http://emoncms.org/input/view) to [Feeds](http://emoncms.org/feed/list). 

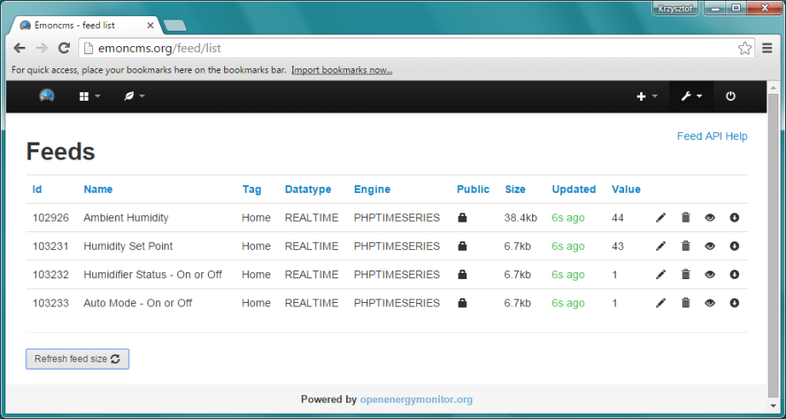
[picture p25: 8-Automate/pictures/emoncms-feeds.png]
Updated Feeds on Emoncms.org


Add *MultiGraph* charts under [Dashboards](http://emoncms.org/dashboard/list)

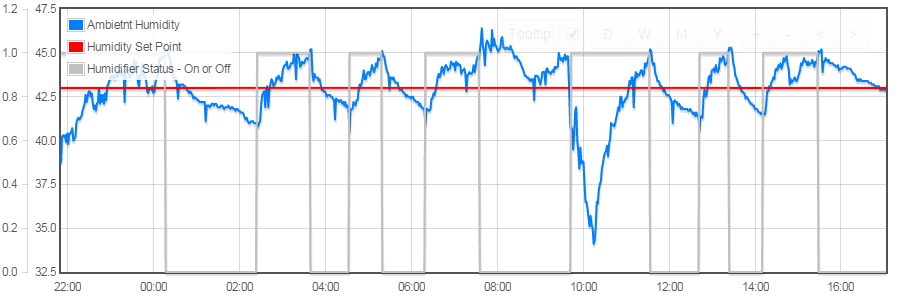
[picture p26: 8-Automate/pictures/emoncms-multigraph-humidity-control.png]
Trends of humidity control on MultiGraph chart


After completion of the above steps leave your control system running in auto mode for couple of hours. This is to collect data for analysis of performance of your humidity control system. Once you have the data, start tweaking the system and observing how this affects quality of humidity control.

This is fun to observe how control system copes with random disturbances (caused by e.g. opening a window, boiling water in kitchen or washing) and trying to get humidity back to the set point. You may improve time to get humidity back on target by changing hysteresis, output of humidifier, location of humidity sensor and data sampling period.

Consider changing one parameters at a time then collecting data for couple of hours and checking results before moving to next parameter.

## Next Step

In section [Maintain](../9-Maintain) I would like to discuss making the code uploads using OTA (Over the Air). This is quicker and more convenient alternative to uploading using a serial port.

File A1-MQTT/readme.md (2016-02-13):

# MQTT

## Table of Contents
  * [Introduction](#introduction)
  * [Required Components](#required-components)
  * [Why MQTT?](#why-mqtt)
  * [Let us do MQTT!](#let-us-do-mqtt)
  * [Send MQTT Message Manually](#send-mqtt-message-manually)
  * [Send Messages from ESP8266](#send-messages-from-esp8266)
  * [Online Humidifier Talks MQTT](#online-humidifier-talks-mqtt)
  * [Make the Topics Meaningful](#make-the-topics-meaningful)
  * [Next Step](#next-step)

## Introduction

The user interface of our [humidity control system](../8-Automate#auto-mode-on) looks somehow crappy. It ended up [this way](../8-Automate#auto-mode-on) in my attempt to keep this guide simple. Once we learned how make this project running using ESP8266, let us make next step and implement some improvements. What we would like to address is functionality of user interface as well as its look and feel.

Currently, to open humidifier UI in web browser, you need to enter IP address your ESP module. The IP may change after next power up. This means you may need to check it on serial monitor to know what to enter. Instead, we should provide easy to remember url that does not change over time. Humidity set point is hard coded. Each time you decide to change the set point, you need to open the sketch in IDE, update it, compile and upload. The interface screen itself is rather crusty and looks like developed 20 years ago :smile:. All these issues may be easy resolved with some effort learning of HTML, coding new web pages and processing these pages by ESP.

But why not to use already tested, well adopted, versatile and mature functionality of an existing open source home automation systems? One of such systems is [openHAB]( http://www.openhab.org/), I am using it myself and would like to present how we can integrate it with ESP8266 module to run process automation application.

Our goal is to convert existing UI screen to user friendly and nicely looking screen like below to run on a Linux or Windows PC as well as on your favourite mobile device.

| Humidifier UI by openHAB in iPhone App | Humidifier UI by openHAB in Chrome | Humidifier UI by openHAB in Android App |
| --- | --- | --- |
| Mac iOS - iPhone | Windows - Google Chrome | Android Samsung Galaxy |

In this section we will lay ground work for interacting with openHAB using [MQTT]( https://en.wikipedia.org/wiki/MQTT) protocol. Configuration and using of openHAB will be subject of next section.

## Required Components

* Online Humidifier h/w and s/w developed in section [Maintain](../9-Maintain)
* [MQTT broker](http://www.hivemq.com/blog/mqtt-essentials-part-3-client-broker-connection-establishment) - do not panic, you can use easy to access public broker before setting up one in your home network. You do not even need to register!

## Why MQTT?

If you are interested in IOT or Home Automation you have likely heard about [MQTT]( https://en.wikipedia.org/wiki/MQTT). This is lightweight protocol well suited to send small chunks of data to communicate between IOT devices. If you compare typical information chunk passed over HTTP to display a typical web blog entry, then MQTT message looks like a post on the Twitter.

To pass messages over MQTT you need a MQTT broker. The broker is a piece of s/w that relays messages from devices that publish MQTT messages to devices that would like to listen to these messages.  A device that would like to listen should subscribe to certain message feed in MQTT broker. You can compare MQTT broker to your home router where you connect your computers and mobile devices to.

The best place to install MQTT broker as a computer on your network that is constantly on, like a home [NAS](http://thewirecutter.com/reviews/best-network-attached-storage/). You may also well install it on a Raspberry PI, BeagleBone, Odroid or another similar small computer that does not consume much energy when on. Before you decide where to install MQTT broker, we can use a [public broker](https://github.com/mqtt/mqtt.github.io/wiki/public_brokers) for time being.

## Let us do MQTT!

Before you rush compiling your sketch I recommend uploading another handy piece of software that is called [mqtt-spy](http://kamilfb.github.io/mqtt-spy/). It will make your start into MQTT word much easier by providing an insight how MQTT message looks like and by helping debugging MQTT communication if required. 

Detailed instructions on installation of mqtt-spy on in [wiki]( https://github.com/kamilfb/mqtt-spy/wiki/GettingStarted) of [mqtt-spy GutHub repository](https://github.com/kamilfb/mqtt-spy). Essentially what you need to do is to install Java suitable for your computer, download and unpack mqtt-spy and run a single file that is inside. The file is in format *mqtt-spy-N.N.N-jar-with-dependencies.jar*, where N.N.N is the latest version number. Once done you will see the following window:

Window opened on initial start of mqtt-spy

Click on *No default configuration file found* banner and then on *Create mqtt-spy configuration file with sample content*. As result another window will pop up:

Creation of sample mqtt-spy configuration

This will make mqtt-spy creating sample connections to public brokers for you:

Window opened on initial start of mqtt-spy

Click *Open test.mosquitto.org*. This is one of available public brokers I have selected for this test. You should see a new tab *test.mosquitto.org* created. Click on that tab. Under *Subscriptions and received messages* you will see */test/#* that is subscription to all messages that have text */test/* at the beginning of its [topic](http://www.hivemq.com/blog/mqtt-essentials-part-5-mqtt-topics-best-practices). Under *Received messages summary* you will see some sample messages:

Opened connection to a public MQTT broker

## Send MQTT Message Manually

Go ahead and publish your message. Enter a topic like */test/manual*, under *Data* type a message *Hello, this is my first MQTT message!* and click *Publish* button. You should immediately see your message bouncing back at the end of *Received messages summary* list.

First sample MQTT message

Congratulations - you have published and received your first MQTT message!

Run-through sending messages to another topic and subscribe (under *Define new subscription*) to this specific topic rather than several topics like */test/#*. Note - the *#* sign is like *** in the filename.

## Send Messages from ESP8266
Now once we have practiced and understood (sort of :wink:) how MQTT works, let us publish messages right from ESP8266. 

To start with we need MQTT client library that will do all complicated stuff for us, so we can focus on our project publishing and subscribing to topics that we will then interface with openHAB.

Let us check [Libraries](https://github.com/esp8266/Arduino/blob/master/doc/libraries.md) in [documentation](https://github.com/esp8266/Arduino#documentation) of esp/Arduino GitHub repository. Luckily, under [Other libraries]( https://github.com/esp8266/Arduino/blob/master/doc/libraries.md#other-libraries-not-included-with-the-ide), we will find  *[PubSubClient](https://github.com/Imroy/pubsubclient) - MQTT library by @Imroy*. Please upload and install this library in Arduino IDE. Information how to do it has been provided [here](../7-Control#install-library). Once installed, please go in Arduino IDE to *File > Examples > PubSubClient* and open *mqtt_basic.ino* sketch.

If you have been following previous sections of [Online Humidifier](../readme.md#step-by-step-tutorial) project, you will find out that most of this sketch contains familiar code to connect to Wi-Fi network. Update then SSID and password to your network.

Now let us configure MQTT. We should start with definition of MQTT client object. In original sketch it looks as below:

```cpp
PubSubClient client(wclient, server);
```

Assuming that we will be using *test.mosquitto.org* broker, we need to update ``` PubSubClient ``` client as below:

```cpp
PubSubClient client(wclient, "test.mosquitto.org");
```

Now we need to update topic we would like to publish our message to. The  code in original sketch that is doing it looks as follows:

```cpp
	client.publish("outTopic","hello world");
```

Let us publish our message to a topic */test/esp8266*. To do so we need to update this line as follows:

```cpp
	client.publish("/test/esp8266","hello world");
```

And that's all we need to do.

Please compile and upload your sketch. Open a serial terminal and check if module has connected to your Wi-Fi. Now there is a moment of truth. If your mqtt-spy was closed then open it and then press reset to restart your ESP8266. You should see the following:

First MQTT message from ESP8266

If you like to see more messages, then reset ESP module again because example sketch is sending the message only once.

After successful completion of this step you are ready to publish MQTT messages to anybody. To retrieve your message the other party should connect to the same MQTT broker and need to know the subject to subscribe to. 

Armed with new know-how, let us make our humidifier talking MQTT!

## Online Humidifier Talks MQTT 

Start off by opening your latest [OnlineHumidifier-Maintain.ino]( ../9-Maintain/OnlineHumidifier-Maintain) sketch and saving is as *OnlineHumidifier-MQTT.ino*. The main file *OnlineHumidifier-MQTT.ino* is packed with code. Now we are about to add even more code. To make the code easer to follow, in the same directory, create a new file *Webserver.ino* and move here all web server functions. Do not forget about adding prototypes of moved function at the beginning of main file *OnlineHumidifier-MQTT.ino* as discussed [here](../9-Maintain#make-first-upload).  

I have moved the following functions to the new *Webserver.ino* file:

```cpp
void setupWiFi(void);
void handleRoot(void);
void handleNotFound(void);
void showControlScreen(void);
void setupWebserver(void);
```

Check if your updated sketch compiles without any errors and if it works exactly the same as the original sketch *OnlineHumidifier-Maintain.ino*. Once this is done you are ready to add MQTT routines.

Open example sketch *mqtt_basic.ino* and start with copying MQTT file #includes and ``` PubSubClient ``` object declaration. Please note name changes to match ``` WiFiClient ``` in our original sketch, i.e. *client* has been changed to *MQTTclient*: 

```cpp
#include <PubSubClient.h>
WiFiClient wclient;
PubSubClient MQTTclient(wclient, "test.mosquitto.org");
```

As the second and last modification copy the code responsible for publishing the message, i.e.:

```cpp
    if (!client.connected()) {
      if (client.connect("arduinoClient")) {
        client.publish("/test/esp8266", "hello world");
        client.subscribe("inTopic");
      }
    }
```

There are couple of updates we need to make to it. As before, please change *client* to *MQTTclient*.  Then alter conditions to publish the message so it is published always if connection is present. In original code the message was published only once after establishing connection to broker. Also enter the name of topic to publish the humidity value to. I propose to make it */test/humidity*. Finally replace *hello world* with humidity value.  As result the code would look as follows:

```cpp
    if (!MQTTclient.connected())
    {
      MQTTclient.connect("arduinoClient");
    }
    if (MQTTclient.connected())
    {
      MQTTclient.publish("/test/humidity", (String) humidity);
    }
    else
    {
      Serial.println("connection failed!");
    } 
```

Then place this code inside the *loop()* to execute every 20 seconds after humidity measurement is made and data are sent to Emoncms.org:

```cpp
  if (millis() % 20000 == 0)
  {
    measureHumidity();
    if (autoMode == true)
    {
      executeHumidityControl();
    }

    sendDataToEmoncms();

    if (!MQTTclient.connected())
    {
      MQTTclient.connect("arduinoClient");
    }
    if (MQTTclient.connected())
    {
      MQTTclient.publish("/test/humidity", (String) humidity);
    }
    else
    {
      Serial.println("connection failed!");
    }
  }
```

Believe or not but this is everything you need to publish humidity value using MQTT protocol. Compile and upload your sketch. Open mqtt-spy and shorty you should see topic */test/humidity* popping up every 20 seconds with current humidity value. Isn't it fantastic?

Message from ESP8266 with dynamic humidity value

## Make the Topics Meaningful

Once the code is publishing humidity value to a test topic, let us publish also other values that describe status of humidity control.  In particular we would like to publish the following information:

* Humidity set point value
* Operation status of humidifier - on or off
* Mode of hygrostat control - manual or auto

With humidity it will be altogether four values to publish. In order not to confuse what we send, let us select proper topic name for each value. Seeing on mqtt-spy several topics published by other people with *test* at the beginning, we definitely should select more meaningful names. I propose as follows:

| Parameter Description | Sketch Variable Name | MQTT Topic |
| --- | --- | --- |
| Ambient humidity | humidity | krzychb/home/sensor/Humidity |
| Humidity set point | humiditySetPoint | krzychb/home/hygrostat/HumiditySetPoint |
| Operation status of humidifier | humidifier | krzychb/home/hygrostat/Humidifier |
| Mode of hygrostat control | autoMode | krzychb/home/hygrostat/AutoMode |

Once topics are defined let us update the sketch.

 Instead of:

```cpp
MQTTclient.publish("/test/humidity", (String) humidity);

```
You can copy and paste the following code:

```cpp
MQTTclient.publish("krzychb/home/sensor/Humidity", (String) humidity);
MQTTclient.publish("krzychb/home/hygrostat/HumiditySetPoint", (String) humiditySetPoint);
MQTTclient.publish("krzychb/home/hygrostat/Humidifier", (humidifier == HIGH) ? "ON" : "OFF");
MQTTclient.publish("krzychb/home/hygrostat/AutoMode", (autoMode == true) ? "ON" : "OFF");
```

In each topic change *krzychb* to your nickname, compile and upload the sketch to the ESP module. Then in mqtt-spy subscribe to *YourNickName/#* and you should see the following:

MQTT messages from ESP8266 with hygrostat parameters

Compete code is saved in GitHub as [OnlineHumidifier-MQTT.ino](OnlineHumidifier-MQTT) - please refer to it in case of issues. Once it is working you are ready to integrate ESP8266 with next exciting software that is called openHAB :smile:

## Next Step

This concludes section how to publish MQTT data from ESP module. In [next section](../A2-openHAB) we would like to use the same routines to send MQTT messages right to openHAB to operate humidifier using user friendly, versatile and well-designed user interface. 
And yes - [openHAB](http://www.openhab.org/) operates on Android and Mac iOS mobile devices as well on Windows and Linux PC.

Online Humidifier controlled from mobile devices 

P.S. BlackBerry will also do the job :smile:

Online Humidifier controlled from BlackBerry

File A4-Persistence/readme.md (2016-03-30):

# Persistence

## Table of Contents
* [Introduction](#introduction)
* [Required Components](#required-components)
* [The rrd4j Persistence](#the-rrd4j-persistence)
* [Configure rrd4j](#configure-rrd4j)
  * [Configure Items](#configure-items)
  * [Configure Charts](#configure-charts)
  * [Install rrd4j Package](#install-rrd4j-package)
* [What About the Sketch? ](#what-about-the-sketch)
* [Conclusion](#conclusion)

## Introduction

["There is no cloud. It's just someone else's computer."](https://www.stickermule.com/marketplace/3442-there-is-no-cloud)

Are you concerned that your sensor data are stored on someone else's computer?  If this is the case then save them on your own PC!  It turns out that it is very easy and you do not need any additional new s/w and h/w than used before. All you need to do is to configure functionally already existing in [openHAB](http://www.openhab.org/). 

In this section I would like to show how to store sensor data using *Persistence* functionality of [openHAB](http://www.openhab.org/) instead of sending them to [Emoncms](https://emoncms.org/). 

## Required Components

* All the components and software used in [section A3-HTTP](../A3-HTTP)

## The rrd4j Persistence

[Persistence](https://github.com/openhab/openhab/wiki/Persistence) is a term used in openHAB for storing item states over time. There several persistence options offered and [rrd4j](https://github.com/rrd4j/rrd4j) (round-robin database) is one of them.  In fact it is default openHAB's persistence. Unlike other databases rrd4j does not grow in size - it has a fixed allocated size. The name *rrd4j* itself may not sound familiar but [rrd4j persistence](https://github.com/openhab/openhab/wiki/rrd4j-Persistence) is well documented on openHAB wiki. Therefore you can refer to wiki to go more into functionality details as this section presents only the bare minimum to get it running.

## Configure rrd4j

There are three things you need to do to get rrd4j running:
  1. Configure items for saving in rrd4j database 
  2. Configure charts to display items
  3. Install rrd4j binding package 

More details are provided below

### Configure Items

There are just four items processed by openHAB (``` Humidity ```, ``` HumiditySetPoint ```, ``` Humidifier ```, ``` AutoMode ```) and let's configure all of them for saving in rrd4j database.  To do so we need to create a configuration file that specifies names of each item to save. Besides that we need to define *Strategies* how often to save each particular item. 

Respective configuration file has name *rrd4j.persist* and looks as follows:

```
Strategies
{
	everyMinute : "0 * * * * ?"
}

Items
{
	Humidity, HumiditySetPoint, Humidifier, AutoMode : strategy = everyChange, everyMinute, restoreOnStartup
}
```
In the above example, for sake of simplicity, we are defining just one *Strategy* named ``` everyMinute ```. The following code ``` "0 * * * * ?" ``` is so called [cron expression](https://en.wikipedia.org/wiki/Cron)  to specify at which exact second, minute, hour, etc. the data should be saved. In our case the sensor data will be saved at 0 seconds of each and every minute.

Then under *Items* comes the list of all items to be saved together with ``` strategy = everyChange, everyMinute, restoreOnStartup ```. This essentially means that each item should be saved on each change as well as every minute. The last strategy means that on openHAB startup, if the value is not defined, the last saved value will be restored from database.

The two strategies ``` everyChange ``` and ``` restoreOnStartup ``` are already statically defined and not listed separately like ``` everyMinute : "0 * * * * ?" ```.

### Configure Charts

We are going to configure two charts. The first will contain ``` Humidity ``` and ``` HumiditySetPoint ``` values. The second will show if humidifier is on or off, as well if control is in auto or manual mode (items ``` Humidifier ``` and ``` AutoMode ```). To do so we first need to define two groups and then specify items belonging to each group. 

The groups will be named ``` HumidityChart ``` and  ``` ControlChart  ``` and are defined in *Items* configuration file as below:

```
Group HumidityChart 	(All)
Group ControlChart 		(All)
```
Then besides particular item we need to add a group name like ``` (HumidityChart) ```. This specifies the group where item belongs to:

```
Number Humidity			"Ambient Humidity [%.0f %%]"	<water>		(HumidityChart)	{http="<[http://192.168.1.114/hygrostat:20000:REGEX(.*?Humidity: (.*?)%<br/>Setpoint.*)]"}
Number HumiditySetPoint	"Humidity Setpoint [%.0f %%]"	<settings>	(HumidityChart)	{http=">[*:GET:http://192.168.1.114/hygrostat?HumiditySetPoint=%2$s] <[http://192.168.1.114/hygrostat:20000:REGEX(.*?Setpoint: (.*?)%<form.*)]"}
Switch Humidifier		"Humidifier"								(ControlChart)	{http=">[*:GET:http://192.168.1.114/hygrostat?Humidifier=%2$s] <[http://192.168.1.114/hygrostat:20000:REGEX(.*?Humidifier: (.*?), switch .*)]"}
Switch AutoMode			"Auto Mode"									(ControlChart)	{http=">[*:GET:http://192.168.1.114/hygrostat?AutoMode=%2$s] <[http://192.168.1.114/hygrostat:20000:REGEX(.*?Auto Mode: (.*?), turn .*)]"}
```

Finally we should specify where to show the charts, what will be the time scale period and how often to refresh each chart. This information is placed in the *sitemap* file and will look as follows:

```
Frame label="Humidity Control Charts" 
{
	Chart item=HumidityChart period=d refresh=6000
	Chart item=ControlChart period=d refresh=6000
}	
```

Statement ``` period=d ``` means that chart will show one day worth of data. Please refer to [openhab](openhab) folder for each of the three configuration files discussed above - [rrd4j.persist](openhab/rrd4j.persist), [default.items](openhab/default.items) and [default.sitemap](openhab/default.sitemap). You need to save each particular file to respective *persistence*, *items* and *sitemaps* folder.

### Install rrd4j Package

The last configuration steep is installation of org.openhab.persistence.rrd4j-N.N.N.jar package (where N.N.N is the version number of your openHAB installation). This package should be placed in *addons* folder like MQTT or HTTP [binding packages](https://github.com/openhab/openhab/wiki/Bindings) discussed previously. This step is done only once to enable rrd4j persistence for your openHAB installation.

## What About the Sketch?

To check rrd4j persistence you can use ESP loaded with exactly the same sketch as prepared in [previous section](../A3-HTTP).  Go ahead, open openHAB in web browser. If configuration described above was done correctly you should see a screen like on samples below.

| openHAB with charts on PC | openHAB with charts on an Android phone | openHAB with charts on an iPhone |
| --- | --- | --- |
| openHAB with charts on a PC | openHAB with charts on an Android phone | openHAB with charts on an iPhone |

But the idea presented in [introduction](#introduction) was to replace Emoncms :smile: Therefore please open [OnlineHumidifier-HTTP.ino](../A3-HTTP/OnlineHumidifier-HTTP) sketch and delete all Emoncms related declarations and procedures. This should be quite easy task as declarations are divided into functional sections and all Emoncms procedures are in a single file. 

Final sketch is saved as [OnlineHumidifier-Persistence.ino](OnlineHumidifier-Persistence).

## Conclusion

The options to do the same or a very similar thing with available free software are enormous. Previous sections provided options to show data using a crude interface made in bare html in a web browser and in a nice interface of openHAB. Other sections provided options to integrate openHAB and ESP using MQTT or HTTP binding. This section presents example of providing data storage and visualization directly on [openHAB](http://www.openhab.org/) home automation platform instead in [Emoncms](https://emoncms.org/) cloud. 

Select what you believe is better, more reliable and simpler for you. Have fun learning how to make good choices and implementing it!

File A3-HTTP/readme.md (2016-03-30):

# HTTP

An openHAB binding alternative to MQTT

## Table of Contents

* [Introduction](#introduction)
* [Ground Work](#ground-work)
* [Issuing Commands](#issuing-commands)
* [Web Page Update](#web-page-update)
* [Sketch Update and Test](#sketch-update-and-test)
* [Only Items to Update](#only-items-to-update)
  * [Issuing Commands](#issuing-commands)
  * [Reading the Information Back](#reading-the-information-back)
* [Check it in Action](#check-it-in-action)
* [Conclusion](#conclusion)

## Introduction

OpenHAB is offering several ways of interfacing with IOT world. Just check the list of available [Bindings and Bundles](http://www.openhab.org/features/supported-technologies.html). Before switching to MQTT I have been using HTTP binding. I was just reluctant to go to MQTT because it required installation of additional s/w and learning a new protocol. In this chapter I would like to present how to use it instead of MQTT – it is possible that you may still feel like me before :smile:
HTTP binding is simpler to implement and offers direct connection to IOT devices as opposed to MQTT that brings a broker in between. On the other hand MQTT provides lightweight protocol and more convenient way to exchange information between any of connected devices. 

Reading this chapter you will have opportunity to check it out using exactly the same h/w and s/w as before. It should be quick and easy job as we will be building on experience gathered going through [previous chapters](../readme.md#step-by-step-tutorial) of this repository. I think that HTTP binding is worth exploring – you will assess and judge by yourself the cons and pros against MQTT binding.

## Ground Work

Using HTTP binding to send commands and retrieving information is like browsing a web page. You issue commands by clicking URLs and retrieving information by looking on contents of displayed web page. To make implementation of this binding possible, we should update the web page served by ESP module. This is so it provides URLs to issue all commands we need, like changing the set point or turning the Auto Mode on and off. It should also display all the information that we are displaying on openHAB. 

Essentially all the commands and information that we would like to see on openHAB, should be available on this web page. We will then use HTTP biding to link this commands and information with nice, user friendly and versatile openHAB interface. Please see below the web page we need, and for comparison the corresponding openHAB UI we have developed previously.

| ESP web page we need | Existing openHAB user interface |
| --- | --- |
| ESP web page we need | Exisitng openHAB UI |

## Issuing Commands

HTTP binding is using URLs to issue commands. We got familiar with such commands in section [Control](../7-Control), chapter [Operate the Socket from Web Browser](../7-Control#operate-the-socket-from-web-browser). For example, to operate humidifier on and off, we have been using URLs as follows:

* ``` http://192.168.1.114/humidifier/1 ``` - to turn humidifier on
* ``` http://192.168.1.114/humidifier/0 ``` - to turn it off

We will use similar concept and slightly adjust it to provide generic way to handle the commands as below:

| # | Command | URL |
| --- | --- | --- |
| 1 | Turn humidifier on  | ``` http://192.168.1.114/hygrostat?Humidifier=ON ``` |
| 2 | Turn humidifier off | ``` http:// 192.168.1.114/hygrostat?Humidifier=OFF ``` |
| 3 | Turn auto mode on  | ``` http:// 192.168.1.114/hygrostat?AutoMode=ON ``` |
| 4 | Turn auto mode off | ``` http:// 192.168.1.114/hygrostat?AutoMode=OFF ``` |
| 5 | Change humidity set point to e.g. 38% | ``` http:// 192.168.1.114/hygrostat?HumiditySetPoint=38 ``` |

It turns out that sketch we have developed already has built in functionality to process such URLs. 

Let's get started. Open recently developed [OnlineHumidifier-openHAB.ino](../A2-openHAB/OnlineHumidifier-openHAB) and save it as *OnlineHumidifier-HTTP.ino*. Compile and upload it to ESP module. 

Once module joins network, open web browser and enter ``` http://192.168.1.114/hygrostat?Humidifier=ON ``` (replace ``` 192.168.1.114 ``` with IP of your ESP). 
You should see result as follows:

Sample GET URL

With some little searching in the *OnlineHumidifier-HTTP.ino* code, you should be able to find the function ``` void handleNotFound(void) ``` that has captured URL we have entered and split it into URI ``` /hygrostat ``` and argument after ``` ? ```. Then the argument is further split into name ``` Humidifier ```and value ``` ON ```.  See details of this function below:

```cpp
void handleNotFound(void)
{
  String message = "File Not Found\n\n";
  message += "URI: ";
  message += server.uri();
  message += "\nMethod: ";
  message += (server.method() == HTTP_GET) ? "GET" : "POST";
  message += "\nArguments: ";
  message += server.args();
  message += "\n";
  for (uint8_t i = 0; i < server.args(); i++) {
    message += " " + server.argName(i) + ": " + server.arg(i) + "\n";
  }
  server.send(404, "text/plain", message);
} 
```

This function is responsible for capturing any URL not processed otherwise by functions ``` server.on ``` or ``` handleRoot ```.

Go ahead and enter ``` http:// 192.168.1.114/hygrostat?HumiditySetPoint=38 ``` (again replace ``` 192.168.1.114 ``` with IP of your ESP :smile:). This one is captured as well with the result as follows:

Sample GET URL

Using function ``` server.on("/hygrostat", []()  ``` that captures specific URI ``` /hygrostat ``` and basing on the above code, we are able to retrieve the name and value pairs for each command. Then it is the matter of using retrieved information to operate our hygrostat. 

The function processing all five commands we need is provided below:

```cpp
server.on("/hygrostat", []() {
  for (uint8_t i = 0; i < server.args(); i++)
  {
    if (server.argName(i) == "Humidifier")
    {
      humidifier = (server.arg(i) == "ON") ? HIGH : LOW;
      actionTransmitter.sendSignal(1, rcDevice, humidifier);
    }
    else if (server.argName(i) == "AutoMode")
    {
      autoMode = (server.arg(i) == "ON") ? true : false;
    }
    else if (server.argName(i) == "HumiditySetPoint")
    {
      humiditySetPoint = server.arg(i).toFloat();
    }
    else
    {
      Serial.println("unknown argument! ");
    }
    Serial.print(server.argName(i));
    Serial.print(": ");
    Serial.print(server.arg(i));
    Serial.printn();
  }
});
```

This function will also print out any argument name, that is not recognized (i.e. other than *Humidifier*, *AutoMode* and *HumiditySetPoint*).

## Web Page Update

Now we should update function ``` showControlScreen() ``` that is serving the web page to display all five URLs / commands discussed above.

```cpp
void showControlScreen(void)
{
  String message;
  message += "<html>";
  message += "<head><meta http-equiv='refresh' content='20'/><title>Online Humidifier</title></head>";
  message += "<body>";
  message += "<h3>Hygrostat</h3>";
  message += "Humidity: " + (String) humidity + "%<br/>";
  message += "Setpoint: " + (String) humiditySetPoint + "%";
  message += "<form action=\"/hygrostat\" method=\"get\">";
  message += "Change <input type=\"text\" name=\"HumiditySetPoint\" size=\"3\" value=\"" + (String) humiditySetPoint + "\"><input type=\"submit\" value=\"Submit\">";
  message += "</form>";
  message += "Humidifier: ";
  if (humidifier == true)
  {
    message += "ON, switch it <a href=\"/hygrostat?Humidifier=OFF\">OFF</a><br/>";
  }
  else
  {
    message += "OFF, switch it <a href=\"/hygrostat?Humidifier=ON\">ON</a><br/>";
  }
  message += "Auto Mode: ";
  if (autoMode == true)
  {
    message += "ON, turn it <a href=\"/hygrostat?AutoMode=OFF\">OFF</a><br/>";
  }
  else
  {
    message += "OFF, turn it <a href=\"/hygrostat?AutoMode=ON\">ON</a><br/>";
  }
  message += "</body>";
  message += "</html>";
  server.send(200, "text/html", message);
}
```

The only new concept in this function, comparing to its original version, is HTML **form** tag. We need it to provide entry field for numeric *Value* that is submitted by ``` http:// 192.168.1.114/hygrostat?HumiditySetPoint=Value ``` request. For more details regarding the **form** tag please check [w3schools.com](http://www.w3schools.com/tags/tag_form.asp).

## Sketch Upload and Test

That completes the key changes to the sketch. Now what you need to do, is removing all the MQTT code that is not required anymore. You can also remove three ``` server.on("/humidifier/… ``` functions. Once done, upload and test the code to check if you can operate all hygrostat functions from the web page.  Open [external serial terminal](https://github.com/esp8266/Arduino/blob/master/doc/ota_updates/ota_updates.md#troubleshooting) to see diagnostic log when checking each function. Final application contains some extra debugging messages printed out over a serial port to help with diagnostics. It is available in this repository saved under [OnlineHumidifier-HTTP.ino](../A3-HTTP/OnlineHumidifier-HTTP). 

Now you can move to configuration of openHAB that is rather straightforward.

## Only Items to Update

We need to update only [default.items](openhab) file and there are two types of updates to be made. First one is for issuing commands and second is for reading the information back from module.

HTTP item binding is similar to MQTT binding [discussed previously](../A2-openHAB/readme.md#items). The only practical difference is that instead of each MQTT topic we are using an URL. All other information for each existing *item* besides inboud and outbund binding stays the same. The two chapters below provide more details on that.

### Issuing Commands

What we need to do is replacement of MQTT outbound binding for with HTTP binding containing URLs that we have prepared [before](#issuing-commands). 

The HTTP binding to switch humidifier on and off looks as follows:

```
>[ON:GET:http://192.168.1.114/hygrostat?Humidifier=ON]
>[OFF:GET:http://192.168.1.114/hygrostat?Humidifier=OFF]
```
As the only difference between both commands is text *ON* and *OFF*, we can compress it to a single statement as below:

```
>[*:GET:http://192.168.1.114/hygrostat?Humidifier=%2$s]
```

The same applies to commands to change the AutoMode and HumiditySetPoint:

```
>[*:GET:http://192.168.1.114/hygrostat?AutoMode=%2$s]
>[*:GET:http://192.168.1.114/hygrostat?HumiditySetPoint=%2$s]
```

Looks simple?  I hope so :smile:

Just remember to replace ``` 192.168.1.114 ``` with IP of your ESP module. And here we are getting to one of potential issues with HTTP binding. If we are using IP addresses instead of domain names, we need to change them in opeHAB configuration each time the IP of respective module changes. With MQTT binding you enter the topic once and then do not need to worry about changes of IP addresses of other devices you communicate with. This task is on shoulders of MQTT broker that relays messages to respective devices basing on topics they subrecibed to.

### Reading the Information Back

The second configuration update is for reading information from the module back to the openHAB. 

Respective command to retrieve ambient humidity will look as follows:

Example of HTTP inbound binding

The first part of this string up to ``` 2000 ``` looks familiar. It is just the URL to the web page served by our ESP module. The rest of the string may look intimidating, but only if you are not familiar with [regular expressions](http://regexone.com/) :smile: 

The expression ``` REGEX() ``` is responsible for searching the webpage returned by ``` http://192.168.1.114/hygrostat ``` to match a specific pattern of characters in order to locate and [extract](http://regexone.com/lesson/capturing_groups) humidity value. To understand how it works, enter ``` http://192.168.1.114/hygrostat ``` address in web browser to open hygrostat screen. Then right click on this screen and select *View source* (or *View page source*, depending on web browser you use). You will see HTML source that would be searched by ``` REGEX() ``` code.  Please see the picture below that explains particular parts of pattern being matched:

Sample GET URL

The text searched like *Humidity* or *Setpoint* looks obvious. The expression ``` .*  ``` will match zero or more occurrences of any character (letter, digit, whitespace, everything).

Below is complete set or regular expressions we need:

| Information to Read | Regular Expression |
| --- | --- |
| Ambient Humidity | ``` REGEX(.*Humidity: (.*?)%<br/>Setpoint.*) ``` |
| Humidity Setpoint | ``` REGEX(.*Setpoint: (.*?)%<form.*) ``` |
| Status of Humidifer | ``` REGEX(.*Humidifier: (.*?), switch it .*) ``` |
| Status of Auto Mode | ``` REGEX(.*Auto Mode: (.*?), turn it .*) ``` |

Now review the same HTML code on picture below against regular expression in table above. See where the information we are looking for is located, and how regular expression is matching the text nearby to extract what we need.

Sample GET URL

I believe you got an idea what regular expressions are about. To go a little more into details I recommend checking [this nice interactive tutorial](http://regexone.com/). You will be able to enter your own regular expressions and instantly check how they work. Do not wait, check it out – learning regular expression using this tutorial is fun!

That is all you need to get HTTP binding to work for you. Please see below complete [default.items](openhab/default.items) configuration file. 

```
Number Humidity			"Ambient Humidity [%.0f %%]"	<water>		{http="<[http://192.168.1.114/hygrostat:20000:REGEX(.*Humidity: (.*?)%<br/>Setpoint.*)]"}
Number HumiditySetPoint	"Humidity Setpoint [%.0f %%]"	<settings>	{http=">[*:GET:http://192.168.1.114/hygrostat?HumiditySetPoint=%2$s] <[http://192.168.1.114/hygrostat:20000:REGEX(.*Setpoint: (.*?)%<form.*)]"}
Switch Humidifier		"Humidifier"								{http=">[*:GET:http://192.168.1.114/hygrostat?Humidifier=%2$s] <[http://192.168.1.114/hygrostat:20000:REGEX(.*Humidifier: (.*?), switch it.*)]"}
Switch AutoMode			"Auto Mode"									{http=">[*:GET:http://192.168.1.114/hygrostat?AutoMode=%2$s] <[http://192.168.1.114/hygrostat:20000:REGEX(.*Auto Mode: (.*?), turn it.*)]"}
```

Again remember to replace ``` 192.168.1.114 ``` with the IP address of your module :smile:. Then upload it to openHAB *configurations/items* directory. The other configuration file, [default.sitemap](openhab/default.sitemap) is exactly the same as we have used [previously](../A2-openHAB#sitemap) setting up MQTT binding.

The last configuration steep is loading org.openhab.binding.http-N.N.N.jar package (where N.N.N is the version number of your openHAB installation) in *addons* folder of your openHAB directory. Loading of such package is required only once when enabling new additional functionality in openHAB.

## Check it in Action

After uploading openHAB configuration, you are finally ready to check it in action with [OnlineHumidifier-HTTP.ino](../A3-HTTP/OnlineHumidifier-HTTP) sketch. Go ahead, open the web page served by ESP module as well as openHAB user interface side by side like shown in chapter [Ground Work](#ground-work). Then operate hygrostat from openHAB. You should see all the changes reflected on ESP web page and vice versa. In case of issues do the troubleshooting using [external serial terminal](https://github.com/esp8266/Arduino/blob/master/doc/ota_updates/ota_updates.md#troubleshooting)  together with openHAB’s OSGI-Console as discussed in [previous section](../A2-openHAB#troubleshooting).

## Conclusion

You had a chance to compare functionality and ease of use of HTTP and MQTT bindings to decide which one better suit your needs.

I believe HTTP binding is a good solution for small IOT networks that consist of couple of devices. For bigger networks it is worth to invest extra effort to setting up MQTT broker and developing of structure of topics to quickly get to specific data. In return, network maintenance and expansion with new devices or type of transmitted information should be easier. Other cons and pros of MQTT and HTTP binding depend on how the data is exchanged between devices. Whether we prefer to ask each time for specific data when needed. Or rather we are just collecting data from numerous devices and prefer to subscribe to specific topics and wait until update arrives.

My favorite chapter when preparing this section was [Reading the Information Back](#reading-the-information-back). This is because it covers regular expressions, which for me represent very efficient and elegant way of processing and extracting text information. I like working with programming languages that have them implemented, like [Perl](https://www.perl.org/).

Explore new tools, make them work for you and have fun!

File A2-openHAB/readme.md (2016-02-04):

# openHAB

## Table of Contents
  * [Introduction](#introduction)
  * [Required Components](#required-components)
  * [Where do I Start with openHAB?](#where-do-i-start-with-openhab)
  * [But how to Operate Humidifier with openHAB?](#but-how-to-operate-humidifier-with-openhab)
    * [Items](#items)
    * [Sitemap](#sitemap)
    * [openhab.cfg](#openhabcfg)
  * [What About ESP8266 Application?](#what-about-esp8266-application)
  * [Troubleshooting](#troubleshooting)
  * [Next Steps](#next-steps)
  * [Conclusion](#conclusion)

## Introduction

Having MQTT communication working, we are only one step ahead from being able to operate our humidity control system from openHAB. The key benefit of using openHAB is mature toolbox of software components to build feature reach and user friendly interface. This platform is vendor-neutral as well as hardware/protocol-agnostic, so you can easy use it on Mac, Linux or Windows and interface with almost any device with support by huge library of [bindings and bundles]( http://www.openhab.org/features/supported-technologies.html). With quick look through this library, among dozens of protocols and of home automation devices, you will discover MQTT protocol.  And it happens we have already implemented this protocol for ESP8266 module in [previous section]( ../A1-MQTT) of this guide :smile: 

Let's then use it with openHAB!

## Required Components

* All the component and software used in [previous section](../A1-MQTT)
* Home Automation Server to install openHAB software - the best would be a separate device like NAS or Raspberry PI. In the meantime you can use the same PC you develop sketches ESP8266

## Where do I Start with openHAB?

You need to [download](http://www.openhab.org/getting-started/downloads.html) and [install](http://www.openhab.org/getting-started/index.html) the following components:

1.	Java - this is a platform for openHAB applications to run,
2.	openHAB Runtime - to set up your home automation server,
3.	openHAB Designer - to configure user interface to our humidity control system,
4.	UI application - to run the user interface on your mobile device.

Go to [downloads](http://www.openhab.org/getting-started/downloads.html) section of openHAB site, select packages suitable for your operating system and download them. For installation instructions click [Getting Started](http://www.openhab.org/getting-started/index.html) link on left. 

Using [those instructions](http://www.openhab.org/getting-started/index.html) complete the following steps:

1. **Installing the openHAB runtime**
2. **Picking your bindings** - in this step please find and save *org.openhab.binding.mqtt-N.N.N.jar* into your openhab/addons directory. It is required to make MQTT work!
3. **Installing the openHAB demo** - this one is marked *optional*, but please complete this step. You need to make sure that openHAB demo configuration is working for you. Only then you can start implementing the user interface for humidity control system.
4. **Installing the openHAB designer** - this step is definitely *required* for us (disregard *optional* in the title). Designer provides user friendly configuration file editor with syntax highlighting and error checking.
5. Skip **Configuring the server** and complete remaining steps:
6. **Start the server!**
7. **Go test it!**
8. **Go mobile!**

Make sure that you are able to see and operate the openHAB demo configuration like below on your PC as well as on your mobile device:

| openHAB demo on a Ubuntu 14.04 LTS Firefox | openHAB demo on Android phone |
| --- | --- |
| openHAB demo on a Ubuntu 14.04 LTS Firefox | openHAB demo on Android phone |

If openHAB demo application is working then proceed to the fun part to build similar screen to operate humidifier!

## But how to Operate Humidifier with openHAB?

If your openHAB installation is running and you verified this using openHAB demo, you are ready to make your own control screen for humidifier.

 Let us develop a screen like below:
 
Humidifier control using openHAB

Sounds like a time consuming task? Not really, and let me show you why :smile: 

To make it running, all you need to do, is to prepare two configuration files with [items](#items) and [sitemap](#sitemap); and enable MQTT broker in a [third file](#openhabcfg).

Now it sounds like a manageable task, isn’t it? Then let us do it :+1:

### Items 

The *items* file contains definition how to exchange data with other systems and how to display it. For instance: how to receive ambient humidity value, how to turn humidifier on and off, or how to display received value in specific format (e.g. with one decimal place or none).

Let us start with how to display information. For our project this file looks as follows:
````
Number Humidity			"Ambient Humidity [%.0f %%]"
Number HumiditySetPoint	"Humidity Setpoint [%.0f %%]"
Switch Humidifier 		"Humidifier"					
Switch AutoMode 			"Auto Mode"
````
You should be able to quickly relate above *items* to what you see on the control screen presented [earlier](#but-how-to-operate-humidifier-with-openhab) in this chapter. Each line starts with item type - in our case *Number* or *Switch*. Then comes the item name and text with description - in openHAB terms the *label text*. In two cases the *label text* includes square brackets with formatting how to display item value.

openHAB Item type

There are couple of other types of items available besides *Number* and *Switch*, for example *String* or *Color*. There are also several [formatting]( http://docs.oracle.com/javase/7/docs/api/java/util/Formatter.html) options. It is moreover possible to show an icon besides an item or group the items. For complete reference please check the section [Explanation of items](https://github.com/openhab/openhab/wiki/Explanation-of-items) in openHAB wiki.

Besides visual presentation, we also need to define how particular item is received and / or how it is send out. In terms of openHAB this is called *binding*.

Below is a sample binding for ambient humidity received using MQTT communication:
```
{mqtt="<[test:krzychb/home/sensor/Humidity:state:default]"}
```
In terms of openHAB the configuration for receiving messages is called *inbound* configuration and marked with < (less than) sign.
 
openHAB Item binding

Likely you recognize the topic *krzychb/home/sensor/Humidity* above. It has been provided in the table at the end of [previous section](../A1-MQTT/ readme.md #make-the-topics-meaningful). We have then specified topics for each parameter published by ESP8266. Now we will use exactly the same topics for receiving these parameters by openHAB as below:

| Parameter Description | openHAB Item Name| MQTT Topic - subscribe / inbound |
| --- | --- | --- |
| Ambient humidity | Humidity | krzychb/home/sensor/Humidity |
| Humidity set point | HumiditySetPoint | krzychb/home/hygrostat/HumiditySetPoint |
| Operation status of humidifier | Humidifier | krzychb/home/hygrostat/Humidifier |
| Mode of hygrostat control | AutoMode | krzychb/home/hygrostat/AutoMode |

To switch humidifier on and off, the binding will look as follows:

```
"(…) >[test:krzychb/home/openhab/Humidifier:command:*:default]"
```

As we are sending information out, this is called *outbound* configuration and marked with > (greater than) sign.

Besides switching humidifier on/off we need to read back information if humidifier is on or off. In such case we combine *inbound <* and *outbound >* configuration. 

Complete definition of an item to switch humidifier on/off, which will also read back humidifier on/off state, will look as follows:

```
Switch Humidifier	"Humidifier"	{mqtt="<[test:krzychb/home/hygrostat/Humidifier:state:default], >[test:krzychb/openhab/hygrostat/Humidifier:command:*:default]"}
```

To distinguish outbound and inbound topics for the same variable, let us slightly modify inbound topic above by replacing *home* with *openhab*:

| Parameter Description | openHAB Item Name| MQTT Topic - publish / outbound |
| --- | --- | --- |
| Humidity set point | HumiditySetPoint | krzychb/openhab/hygrostat/HumiditySetPoint |
| Operation status of humidifier | Humidifier | krzychb/openhab/hygrostat/Humidifier |
| Mode of hygrostat control | AutoMode | krzychb/openhab/hygrostat/AutoMode |

Complete *items* file for our humidity control looks as follows:

```
Number Humidity			"Ambient Humidity [%.0f %%]"	<water>		{mqtt="<[test:krzychb/home/sensor/Humidity:state:default]"}
Number HumiditySetPoint	"Humidity Setpoint [%.0f %%]"	<settings>	{mqtt="<[test:krzychb/home/hygrostat/HumiditySetPoint:state:default], >[test:krzychb/openhab/hygrostat/HumiditySetPoint:command:*:default]"}
Switch Humidifier		"Humidifier"								{mqtt="<[test:krzychb/home/hygrostat/Humidifier:state:default], >[test:krzychb/openhab/hygrostat/Humidifier:command:*:default]"}
Switch AutoMode			"Auto Mode"									{mqtt="<[test:krzychb/home/hygrostat/AutoMode:state:default], >[test:krzychb/openhab/hygrostat/AutoMode:command:*:default]"}
```

Create a text file, named it *default.items*, copy to it the configuration above and save in your *openhab/configurations/items* directory. Then open it using openHAB Designer, replace ```krzychb``` with your nickname and save the changes.

In this file you may have noticed text ``` <water> ``` and ``` <settings> ``` that was not described before. Each such text represents an icon that will be displayed besides particular item. For available icons please check contents of * /openhab/webapps/images* directory.  Yes, you can display your own images after adding them to this directory and updating the *items* file :+1:

For other options concerning MQTT binding, please refer to [MQTT binding section](https://github.com/openhab/openhab/wiki/MQTT-Binding) of openHAB wiki.

### Sitemap

Are your still with me? I hope yes. Do not freak out - this one is easier :smile: 

The *sitemap* is the second configuration file we should prepare. It is used to define the structure and contents of your user interface. With just couple of lines of code you can distribute and organize *items* on one or more screens, as well as make adjustment to visualization of *items*. 

In our case the file looks as below:

```
sitemap default label="Home"
{
	Frame label="Hygrostat" 
	{
		Text item=Humidity
		Setpoint item=HumiditySetPoint minValue=20 maxValue=80 step=1
		Switch item=Humidifier
		Switch item=AutoMode
	}
}
```

You should quickly recognize the label “Home” which is the name of the screen displayed at the top. Then you will see a frame labelled “Humidifier”, that groups the four items we have defined previously and saved in [default.items](openhab/defalt.items) file.  Items *Humidity*, *Humidifier* and *AutoMode* are rendered using formatting defined in [default.itmes](openhab/default.itmes). ``` HumiditySetPoint``` is slightly modified by the sitemap. First, it is rendered as *Setpoint*, that means on the screen you will see additional signs - either +/- or ^/v to allow value adjustment. Second, the sitemap provides limits within which the value may be changed (in that case from 20 to 80), and the change step value (here the step is 1, and you can enter other values).

Save this file in your *openhab/configurations/sitemaps* directory using name *default.sitemap* and you are done.

Please note that the text *default* in first line corresponds with file name of *default.sitemap*.  If at some point you change the file name to e.g. *garage.itmes*, you should also change this text to *garage* as well. Otherwise the *Setpoint* may not work correctly.

### openhab.cfg

The last step concerning openHAB is update of *openhab.cfg* configuration file.  This one is even easier. Start openHAB Designer, open this file from *openhab/configuration* directory and locate *MQTT Transport* section. The part that you are concerned with looks as follows:

```
#######################################################################################
#####                       Transport configurations                              #####
#######################################################################################

################################# MQTT Transport ######################################
#
# Define your MQTT broker connections here for use in the MQTT Binding or MQTT
# Persistence bundles. Replace <broker> with a id you choose.
#

# url to the MQTT broker, e.g. tcp://localhost:1883 or ssl://localhost:8883
#mqtt:<broker>.URL=tcp://<host>:1883
```

All the lines above start with *#* that means they are just comments and got ignored by openHAB.

Reading these comments we can figure out three required changes as follows:
1.	Replace <broker> with *test* - as this is the broker alias used in *default.Items* file,
2.	Replace <host> with *test.mosquitto.org*,
3.	Remove the comment sign *#* in front of this line so it becomes the configuration command interpreted by openHAB.

After entering all above changes this line should look as follows:

```
mqtt:test.url=tcp://test.mosquitto.org:1883
```

That is it, and that simple :smile:. 

Save the changes, launch the runtime by executing the script *start.bat* (if you are running Windows) or *start.sh* (if you are on Linux or Mac). After a few seconds (depending on the speed of your computer), you should be ready to check what will be now displayed by openHAB!

Open a web browser and enter the following URL, replacing ``` openHAB_IP_Address ``` with IP address of computer where you have installed openHAB:

```
http://openHAB_IP_Address:8080/openhab.app
```

For instance, if IP of computer with openHAB is 192.168.1.119, then complete URL will be ``` http:// 192.168.1.119:8080/openhab.app ```. Please note that the computer with openHAB and the computer where you open the web browser should be on the same network.

If your mobile device is connected to the same network as well, you can open openHAB UI in dedicated mobile application. Such applications are available for iOS, Android and Pebble - please check “UI applications” in [downloads section](http://www.openhab.org/getting-started/downloads.html) of openHAB web page.

After installing the application and running it, opeHAB server should be discovered automatically. This is assuming your device is on the same network as your openHAB server. In case of issue with automatic discovery, enter the following URL in *Settings > openHAB URL*:

```
http://openHAB_IP_Address:8080
```
 
 Android openHAB application settings

Again substitute ``` openHAB_IP_Address ``` with IP address of computer where you have installed openHAB server.

If your ESP is connected to Wi-Fi network and running *OnlineHumidifier-MQTT.ino* created in [previous section](../A1-MQTT/OnlineHumidifier-MQTT), you should see the following in mobile application as well as in web browser:

| Hygrostat on Windows 7 Google Chrome | Hygrostat on Android phone |
| --- | --- |
| Hygrostat on Windows 7 Google Chrome | Hygrostat on Android phone |

If you operate controls on the screen by changing Humidity Setpoint and toggling the switches, you should see on mqtt-spy respective messages passed over MQTT:

Initial messages published by openHAB inmqtt-spy

## What About ESP8266 Application?

Sure, now once openHAB is listening to ESP module, it is time to close the loop and make ESP module listening to openHAB. 

Exactly as we have subscribed mqtt-spy to receiving messages published by ESP or openHAB, now we need to subscribe ESP module to receiving messages published by openHAB.

Start off by opening sketch [OnlineHumidifier-MQTT.ino](OnlineHumidifier-MQTT)  and saving it as OnlineHumidifier-openHAB.ino.

To subscribe you need to enter the following single line of code:

``` cpp
    MQTTclient.subscribe("krzychb/openhab/hygrostat/#");
```
Execute this code each time you are connecting (or reconnecting) to the MQTT broker. As result you will subscribe ESP8266 to receiving any MQTT message that begins with *krzychb/home/openhab/*.

Once a message to such subject is received, it will trigger the callback function *MQTTcallback*. Inside this callback function, we need to look up for specific topic and act accordingly:

``` cpp
void MQTTcallback(const MQTT::Publish& pub)
{
  if (pub.topic() == "krzychb/openhab/hygrostat/HumiditySetPoint")
  {
    humiditySetPoint = pub.payload_string().toFloat();
  }

  if (pub.topic() == "krzychb/openhab/hygrostat/Humidifier")
  {
    humidifier = (pub.payload_string() == "ON") ? HIGH : LOW;
    actionTransmitter.sendSignal(1, rcDevice, humidifier);
  }

  if (pub.topic() == "krzychb/openhab/hygrostat/AutoMode")
  {
    autoMode = (pub.payload_string() == "ON") ? true : false;
  }
}
```
More specifically, this code is checking ``` pub.topic()  ``` that provides the topic to which the message arrived.  Depending on the code, specific action is performed using the value provided by ``` pub.payload_string()  ```.  For example, if the topic is ``` krzychb/openhab/hygrostat/Humidifier ```, and the value provided by ``` pub.payload_string()  ``` is ``` ON ```, ESP should  switch the humidifier on.

OK, there are two more things we need to do.

First, we need to register the callback function *MQTTcallback* discussed above. To do so, place the following code in ``` setup() ```:

``` cpp
  MQTTclient.set_callback(MQTTcallback);
```  

Second, we need to periodically check if MQTT connection is alive and call ``` MQTTclient.loop() ``` to process incoming messages. We will enclose these two actions in a single function ``` MQTTkeepAlive() ``` as follows:

``` cpp
void MQTTkeepAlive(void)
{
  if (!MQTTclient.connected())
  {
    MQTTclient.connect(MQTTclientName);
  }
  else
  {
    MQTTclient.loop();
  }
}
```

The complete ``` loop() ``` including call to the above function is shown below.

```cpp
void loop(void)
{
  ArduinoOTA.handle();
  server.handleClient();
  MQTTkeepAlive();

  if (millis() % 45000 == 0)
  {
    measureHumidity();
    if (autoMode == true)
    {
      executeHumidityControl();
    }
    sendDataToEmoncms();
    MQTTpublishData();
  }
}
```

The complete code is available in this GitHub repository as [OnlineHumidifier-openHAB.ino](OnlineHumidifier-openHAB). It contains some extra diagnostic messages to make debugging easier. Please review it if you follow all the changes made. Then replace ``` krzychb ``` in all topics with your nickname, compile and upload it to your ESP module. Do not forget about updating SSID and password to your Wi-Fi network. 

If nothing is missed, then you will be able to change humidity set point, switch humidifier on/off and toggle the hygrostat’s auto mode using openHAB.

## Troubleshooting

For each particular piece of software and hardware discussed in this guide, use specific troubleshooting tools discussed before. Below is summary for troubleshooting of MQTT communication and ESP8266 application. 

Use mqtt-spy as a simple and effective way to check what MQTT messages are sent between openHAB and ESP module, if they are sent to desired topic, and if they contain expected value. If required, publish test messages [directly from mqtt-spy](../A1-MQTT#send-mqtt-message-manually).

To see what ESP application is doing, use [external serial terminal](https://github.com/esp8266/Arduino/blob/master/doc/ota_updates/ota_updates.md#troubleshooting). The [OnlineHumidifier-openHAB.ino](OnlineHumidifier-openHAB) sketch includes some extra diagnostics messages. They will help to follow what module is currently doing and what MQTT messages send by openHAB are captured by ``` MQTTcallback ``` function. 

OnlineHumidifier-openHAB.ino log on serial terminal

I recommend checking the log on serial terminal to assess time required to send data to Emoncms.org and publish MQTT messages. Then verify how this affects application functionality. Depending on your network it may take couple of seconds to send the data out. When this happens, as the s/w is operating now, the module is not processing incoming MQTT messages. Please check it by trying to change humidity set point from openHAB when you see module transmitting data to Emonsms.org. This will not work and looks like good opportunity to make improvements in application so processing of commands from openHAB is not blocked by other operations on ESP module.

For such testing you need to get familiar with another useful tool - the openHAB’s OSGI-Console. This console is my primary tool for troubleshooting as it provides detailed log of each command sent out, each value update or command received. In case of traceable errors you will see specific error messages as well. The typical log looks like below:

openHAB console log with demo and hygrostat running

If your demo configuration is running, this log gets crowded with messages that you may not be interested in. If number of messages becomes the issue to catch information on update of specific item, just remove demo files from *openhab/configuration* folder. The log of openHAB processing only hygrostat application looks much clear and should be easier to analyze:

openHAB console log with only hygrostat running

## Next Steps

If you like this application and planning to use it, think how to make it more reliable and permanent. Below are some ideas:

1.	Install openHAB on a standalone platform like NAS, Raspberry PI, BeagleBone, Odroid or another similar computer. Then you can have openHAB running continuously and independently from your PC.
2.	Install MQTT broker on the same platform as openHAB to get independent from public broker. Each MQTT messages now travels all the way to test.mosquitto.org and back! 
3.	Solder components on a proto board and put them in an enclosure. This is to protect your hygrostat from malfunction because of bad contacts, disconnecting some component or damage.

## Conclusion

I hope you agree that building easy to operate and nicely looking user interface with openHAB is easy. You get the same functionality, look and feel of interface on Windows, Linux and Mac computer as well as on iOS and Android mobile devices. I really like such flexibility. This way, after configuring openHAB only once, everybody can use it on their favorite platform. 

The good news is that the Online Humidifier example provided this section shows only a fraction of functionality available with openHAB. Go ahead, explore it together with ESP8266 or other microcontrollers and have fun!

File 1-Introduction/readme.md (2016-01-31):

# Introduction

Each winter I am getting concerned about humidity in my home. When it is cold outside we keep the windows closed most of the time so humidity is going either too high or too low. This depends on your heating system, ventilation, how often you cook, take shower, wash and couple of other factors.

To reduce excessive humidity you can use [dehumidifier](https://en.wikipedia.org/wiki/Dehumidifier). If it is too low you can increase it with a [humidifier](https://en.wikipedia.org/wiki/Humidifier).
You can [ask google to find recommended level of humidity](http://www.azosensors.com/Article.aspx?ArticleID=487) so you and your family feel comfortable and your window panes do not getting fogged.

My optimum humidity level is about 40 - 45%. During autumn it stays about 45% - 50% if it is raining outside and temperature is high enough so I can keep the windows open. During winter it quickly drops below 30% unless I use humidifier.

My humidifier has manual control which makes great opportunity for a home automation project. The plan is to measure humidity and if it is below desired target value - turn the humidifier automatically on. In opposite situation, if humidity is above target– turn humidifier off.

The task for this automatic control is to maintain target humidity no matter how often I open windows or boil water for a cup of tea.

This GitHub repository is to show step by step how to do it. Check it out - this is not difficult, does not cost much at all and you will have fun and satisfaction making it happen.

## So What Next?

Go ahead and check [Components](../2-Components) section what you need to build this nice project :smile::+1:

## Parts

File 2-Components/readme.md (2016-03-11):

# Components

What kind of hardware and software you need.

## Table of Contents

* [Hardware](#hardware)
  * [Humidifier and RC Socket](#humidifier-and-rc-socket)
  * [Microcontroller and I/O](#microcontroller-and-io)
  * [Miscellaneous](#miscellaneous)
  * [Hardware Bill of Materials](#hardware-bill-of-materials)
  * [Other Hardware Options](#other-hardware-options)
* [Software](#software)
  * [Software Bill of Materials](#software-bill-of-materials)
* [I have all Required Components - What Next?](#i-have-all-required-components---what-next)

## Hardware

### Humidifier and RC Socket

To build this project you need a humidifier. Look for simple one with manual control and big enough water container suitable for the size of your flat. Mine has 4.2 l (0.9 gal) container and is rated for 17 m2 (183 sq. ft) room. Basing on my experience, if you run it at most output, it will easy cover 2 – 3 x larger area of a typical 2.7 m (8.9 ft) high flat.  But if you set it at maximum, you may need to place it on a chair or a table so mist is able to disperse before wetting the floor.

You need to be able to switch humidifier remotely on and off depending on ambient humidity. I decided to use RC socket for this purpose. This is safe, simple and cheap solution. Such sockets are around for several years, easy to buy and control. I recommend one with LED to see instantly if it is on or off. 

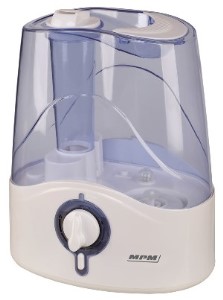
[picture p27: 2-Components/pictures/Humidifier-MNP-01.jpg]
Humidifier
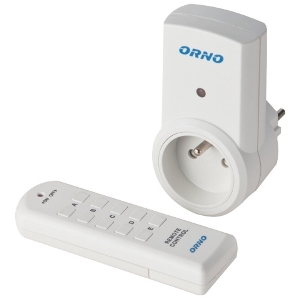
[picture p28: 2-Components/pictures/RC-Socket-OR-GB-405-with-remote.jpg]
RC Socket and Remote Control
|  |   |
| --- | --- |
| Humidifier | RC Socket with Remote |

When searching for the RC socket, look for a model that operates in RF 433 MHz frequency band. Information about that is typically placed on the package, in specification as well as on the socket and remote control - see picture below: 

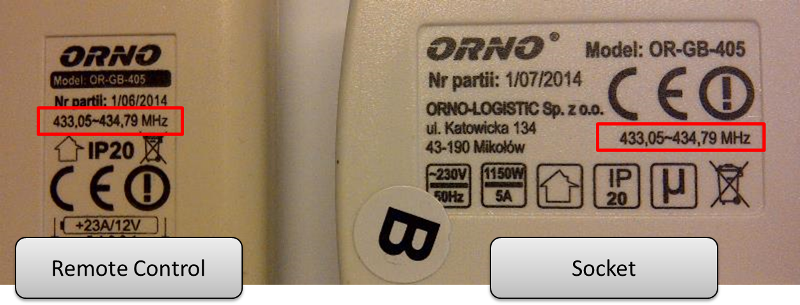
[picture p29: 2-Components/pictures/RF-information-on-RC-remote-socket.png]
RF information on RC remote and socket


### Microcontroller and I/O

Automatic control will be done by microcontroller. I have selected NodeMCU 1.0 that has ESP8266 Wi-Fi on board, 4MB flash memory, mini USB port and is really easy to program with Arduino IDE.

Next key component is humidity sensor that we should hook up to our microcontroller.

The last key piece is a radio transmitter to operate RC socket as if using the remote control. Do not be scared. Such transmitter is really easy to hook up and operate by a microcontroller.

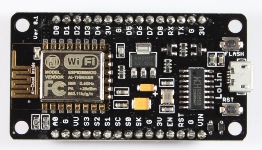
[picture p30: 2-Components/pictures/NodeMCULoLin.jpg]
LoLin NodeMCU
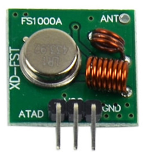
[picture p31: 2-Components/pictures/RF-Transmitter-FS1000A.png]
RF Transmitter
|  | Humidity Sensor |  |
| --- | --- | --- |
| ESP8266 | Humidity Sensor | RF Transmitter |

### Miscellaneous

You will also need some minor stuff like jumpers or breadboard and I will discuss it once we come to the details. 

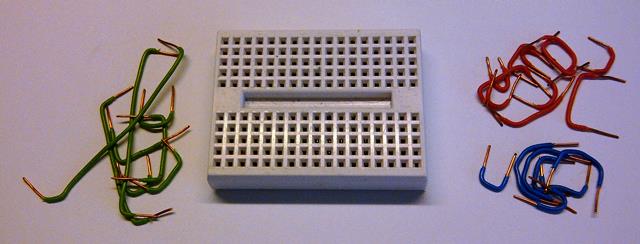
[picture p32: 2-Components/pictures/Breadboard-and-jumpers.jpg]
Breadboard and Jumpers


### Hardware Bill of Materials

Here are exact models I am using.

*	Humidifier - **MPM, model MNP-01**
*	RC Socket - **ORNO (R), model OR-GB-405**
*	ESP8266 - **LoLin NodeMCU V3 by wemos.cc**
*	Humidity Sensor - **AM2302 by AOSONG**
*	RF Transmitter - **RF 433, model FS100A**

To buy humidifier and RC socket go to your local store with electric household appliances. 

Remaining three components: ESP8266, humidity sensor and radio transmitter you can easy buy on-line. 

### Other Hardware Options

You may consider reduction of number of hardware components by using an ESP8266 relay board like below:

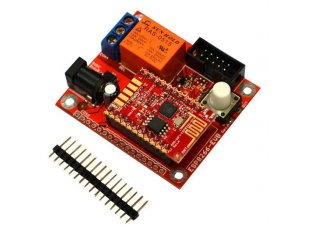
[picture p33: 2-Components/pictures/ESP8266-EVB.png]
ESP8266-EVB by Olimex
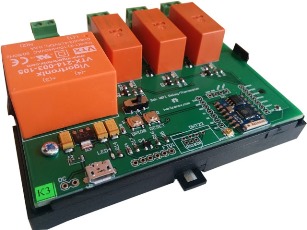
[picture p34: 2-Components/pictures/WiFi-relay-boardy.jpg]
3CH Wi-Fi Relay Control Board by Martin Harizanov
|  |  |
| --- | --- |
| ESP8266-EVB by [Olimex]( https://www.olimex.com) | 3CH Wi-Fi Relay Control Board by [Martin Harizanov](https://harizanov.com/) |

There are the following cons and pros of such solution:

* (+) smaller number of components / RF transmitter and RF socket will not be required
* (+) smaller footprint of solution if ESP8266-EVB relay board is used
* (+) ESP8266-EVB relay board may be possibly hidden inside of humidifier housing / self-enclosed solution - no external components
* (+) external DC power supply not required if 3CH Wi-Fi Relay Control Board is used
* (-) humidity sensor may be too close to humidifier / measurements may be exaggerated when humidifier is on
* (-) need to build external housing for relay board (if not mounted inside humidifier)
* (-) external USB / serial converter is required / less experienced may be discouraged
* (-) solution not recommended for users not experienced with handling of mains power

Another option to consider is using RC socket that has ESP8266 already build in. Such sockets should be soon widely available. Check [this thread]( http://www.esp8266.com/viewtopic.php?p=37583#p37583) on ESP8266 Community Forum for initial information.

## Software

We will build this project using open source software - primarily Arduino IDE and ESP8266 core for Arduino.
Besides that we will also need Arduino libraries for humidity sensor and RF transmitter.

### Software Bill of Materials

Below are the links to the software we need:
* Arduino IDE - https://www.arduino.cc/
* ESP8266 core for Arduino - https://github.com/esp8266/Arduino
* Humidity sensor library - https://github.com/adafruit/DHT-sensor-library
* RF transmitter library - http://randysimons.nl/26-433mhz-libraries-for-arduino

## I have all Required Components - What Next?

Check section [Setup](../3-Setup) to learn how to compile and download your first sketch and make a LED blinking :star2:

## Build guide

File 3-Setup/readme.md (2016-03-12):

# Setup

Programming of ESP8266 SoC microcontroller with Arduino IDE is really straightforward. See below how to quickly go up to speed :zap:

## Table of Contents

* [What You Need](#what-you-need)
* [Configure IDE](#configure-ide)
* [Hook up Your ESP Module](#hook-up-your-esp-module)
* [Upload Example Sketch](#upload-example-sketch)
* [Tweaking Your Sketch](#tweaking-your-sketch)
* [What Do We Do Next?](#what-do-we-do-next)

## What You Need

To start programming ESP8266 with Arduino IDE you need just three things:

*	PC where we install Arduino IDE
*	ESP8266 board with USB port – see [Components](../2-Components)
*	USB cable

## Configure IDE

To start with, install Arduino IDE and ESP8266 board support. Please go ahead and follow instructions in chapter [Installing with Boards Manager](https://github.com/esp8266/Arduino#installing-with-boards-manager) under https://github.com/esp8266/Arduino. This project is using Arduino IDE **1.6.5** together with version **2.0.0** of ESP8266 platform package.
 
Once installation is successfully completed, in Board menu, we will see several ESP8266 boards that are supported by ESP8266 core for Arduino.

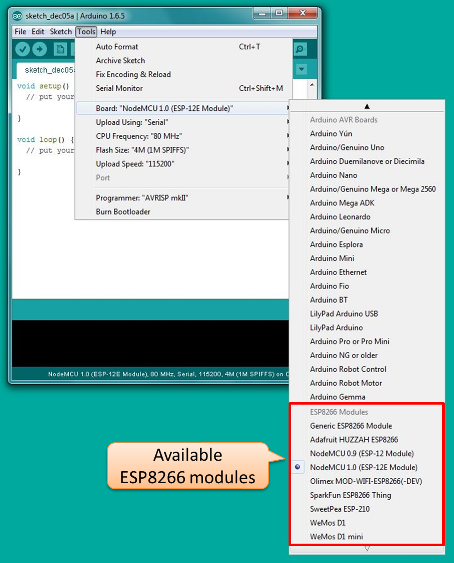
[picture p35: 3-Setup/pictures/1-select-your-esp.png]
Select your ESP from Boards menu


Select board you have. In my case it is NodeMCU 1.0. I like using it for development because it does not require external USB to serial converter and power supply. All you need to connect is micro USB cable and you are ready to go. If you are using another board, please select what you have.

## Hook up Your ESP Module

Now connect ESP to USB port in your PC. After it is recognized by the system you will see it in Ports menu. Select port where your ESP is connected to.

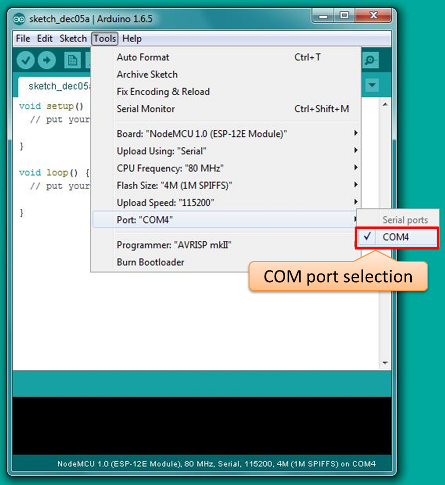
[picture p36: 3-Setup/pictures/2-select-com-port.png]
Selection of board from Ports menu


If your board is not recognized you may need to download and install USB driver. For NodeMCU 1.0 board, depending on model you   typically need either [CH340G](http://www.wch.cn/download/CH341SER_EXE.html) or [CP2102](https://www.silabs.com/products/mcu/Pages/USBtoUARTBridgeVCPDrivers.aspx) driver.

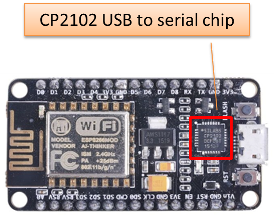
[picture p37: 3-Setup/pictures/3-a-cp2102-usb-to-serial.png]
NodeMCU 1.0 with CH340G USB Chip
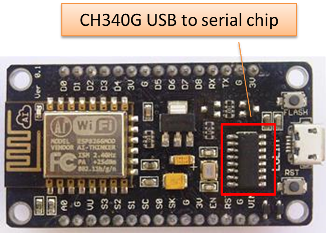
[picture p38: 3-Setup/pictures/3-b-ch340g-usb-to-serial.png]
NodeMCU 1.0 with CP2102 USB Chip
|  |  |
| --- | --- |
|  NodeMCU 1.0 with CH340G USB to serial chip | NodeMCU 1.0 with CP2102 USB to serial chip |

## Upload Example Sketch

We should be ready now to upload our first sketch to ESP. Please go to File > Examples > ESP8266 and select Blink.ino. 

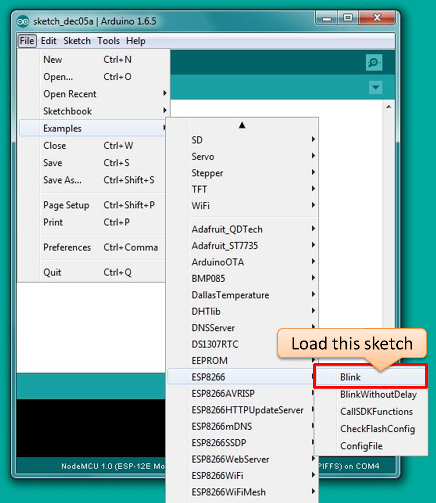
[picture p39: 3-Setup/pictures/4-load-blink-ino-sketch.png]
Selection of Blink.ino sketch


Then just press Upload. The sketch will be first compiled and then upload to ESP. Once this is complete you will see that LED on your ESP module is blinking. 

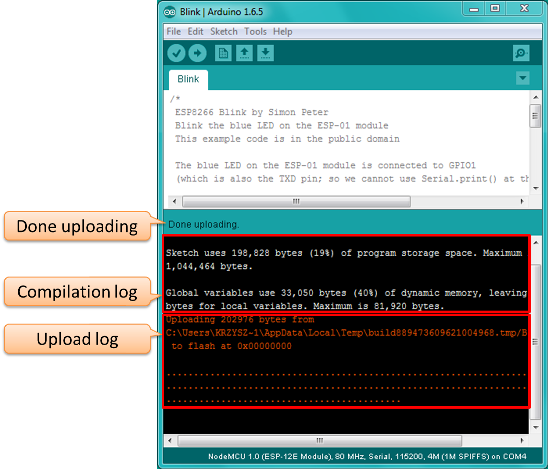
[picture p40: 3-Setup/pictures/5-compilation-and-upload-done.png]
Compilation and upload complete


Congratulations! You have just compiled and uploaded your first sketch!

## Tweaking Your Sketch

If LED is not bilking this may be because of incorrect LED pin number coded behind BUILTIN_LED define. Replace all occurrences of BUILTIN_LED with LED pin number appropriate for your board. For NodeMCU LoLin I have, the BUILTIN_LED should be 2. Please see on the screenshot below updates I have made.

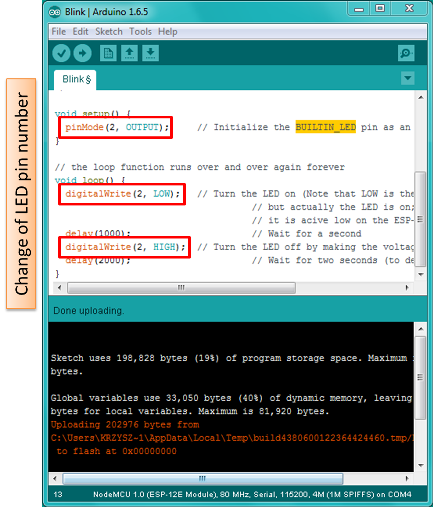
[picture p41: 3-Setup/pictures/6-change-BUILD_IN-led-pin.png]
Changed BUILTIN_LED directly to pin number


If led is blinking, go ahead and change one of both delays. Upload program to see different blinking pattern.

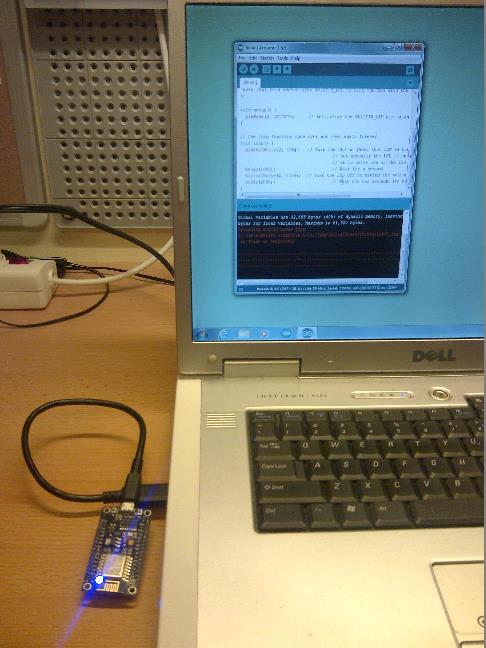
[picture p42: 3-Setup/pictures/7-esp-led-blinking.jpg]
NodeMCU 1.0 with LED blinking


## What Do We Do Next?

If you are comfortable with controlling blink pattern of LED you can go to the next step - hook up humidity sensor and prepare a program to make some measurements. This is discussed in chapter [Measure](../4-Measure) of this tutorial.

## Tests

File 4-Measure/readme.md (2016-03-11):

# Measure

In previous section we have [setup Arduino IDE for ESP8266 programming](../3-Setup). Now we are ready to connect humidity sensor to our ESP and make some humidity measurements. 

## Table of Contents

* [What You Need](#what-you-need)
* [Hardware Setup – the Breadboard Time](#hardware-setup--the-breadboard-time)
* [Software Setup](#software-setup)
* [Next Step](#next-step)

## What You Need

* PC and ESP8266 board set up in [previous step](../3-Setup).
* DHT22 humidity and temperature  sensor
* 5 to 10 kOhm resistor
* Breadboard
* Some jumpers

For additional details please refer to section [Components](../2-Components)

## Hardware Setup – the Breadboard Time

First please connect DHT22 sensor, resistor and ESP module as shown on [schematics](esp8266-dht22.fzz) below.

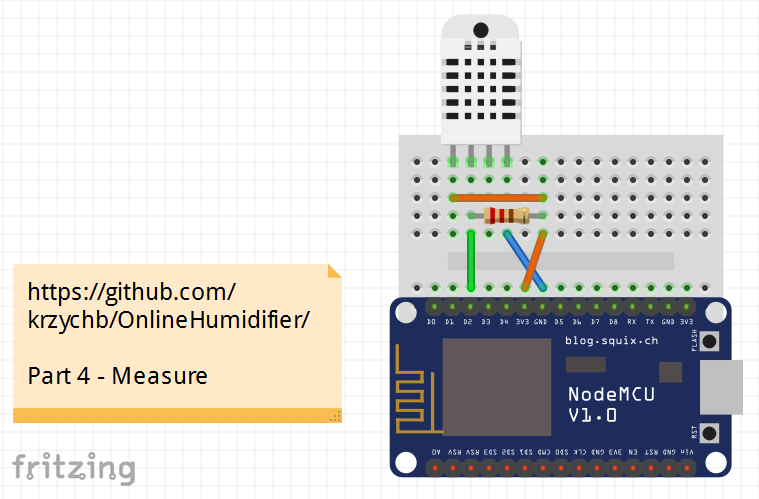
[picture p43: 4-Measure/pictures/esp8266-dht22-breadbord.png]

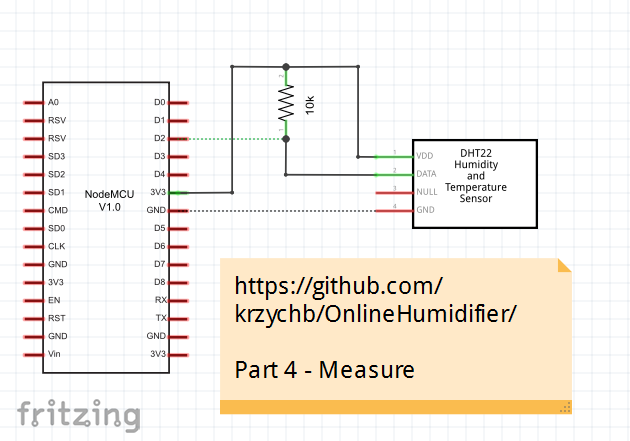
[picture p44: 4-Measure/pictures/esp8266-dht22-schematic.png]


As you may notice we are connecting 3.3V and GND taken from ESP to first and forth pin of DHT22 – this will provide power supply for the sensor. Second pin provides humidity measurement. It is connected to input D2 of ESP. It is also connected to a resistor that pulls this pin up to 3.3V. Communication between sensor and ESP is done using a custom serial protocol. If you are interested in details please check DHT22/AM2302 sensor [data sheet](pictures/AM2302.pdf). 

## Software Setup

Once hardware connections are ready let us prepare the software. I have mentioned that ESP is communication with DHT22 sensor over a custom protocol.  This protocol has been already implemented for Arduino in a [DHT sensor library](https://github.com/adafruit/DHT-sensor-library) that we can use instead of writing it by ourselves. To do so we first need to install it. Go to Sketch > Include Library > Manage Libraries... and type “DHT” in search box. Pick “DHT sensor library” and install it. 

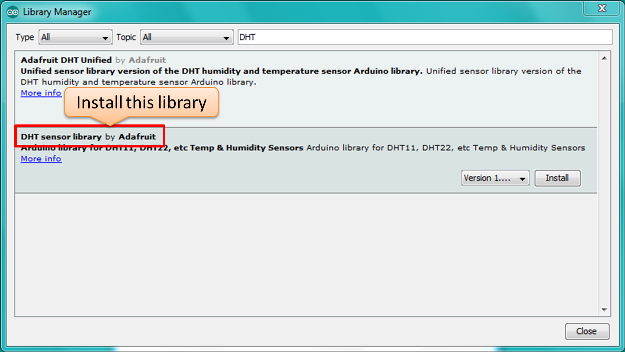
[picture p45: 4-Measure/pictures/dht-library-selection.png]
DHT library selection


Once library is installed, go to File > Examples > DHT sensor library and pick DHTtester.ino sketch. Now in the sketch we need to verify the pin number where DHT22 is connected to. In sketch is entered as ``` #define DHTPIN ``` with value of 4. In my case (check the schematic above) it is D2, so I need to replace 4 with D2. 

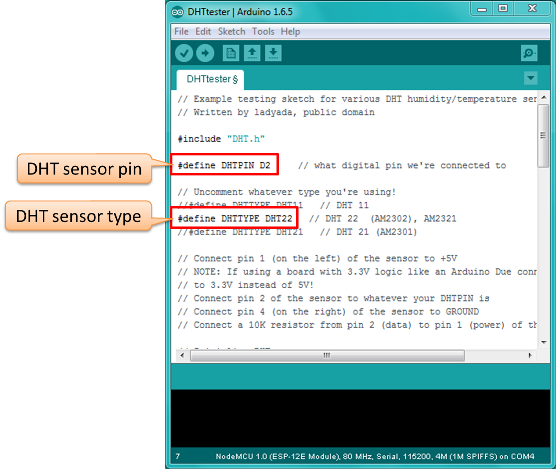
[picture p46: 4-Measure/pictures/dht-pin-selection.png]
Update DHT pin number


You may need to adjust the pin number, if you are using different board. Please note the ``` #define DHTTYPE DHT22 ``` below that specifies DHT22 that is the sensor type we are using.  If you are using different type of DHT then comment line with DHT22 and uncomment another line with your sensor type. 

After ``` DHTPIN ``` and ``` DHTTYPE ``` are set up to match your configuration click upload.

Once upload is complete open Serial Monitor (Ctrl+Shift+M). If you see garbage on the screen over and over then verify baud rate of Serial Monitor. 

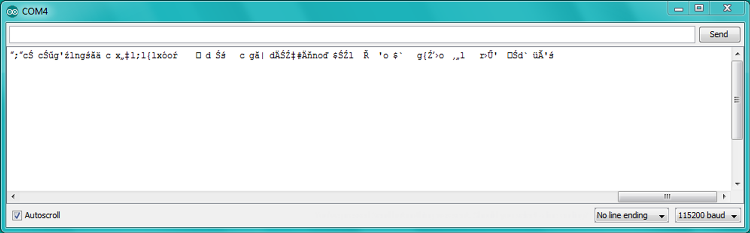
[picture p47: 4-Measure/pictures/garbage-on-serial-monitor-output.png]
Garbage on Serial Monitor


In the sketch the baud rate it is setup to 9600 bits per second. Check if the same value is selected on Serial Monitor. If this is done and sensor is correctly connected, you should see humidity and temperature values updated every second.

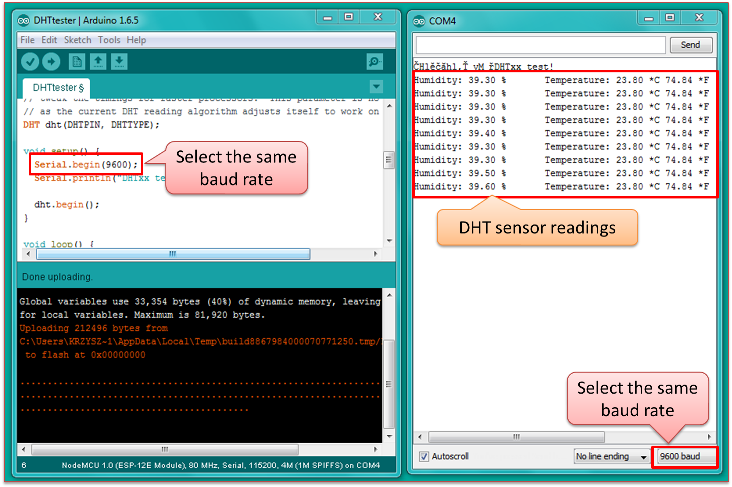
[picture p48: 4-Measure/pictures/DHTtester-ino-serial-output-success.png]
Serial Monitor output – sensor read successful


You will still see some garbage characters just after reset. This is normal behavior as initially module outputs data on serial at 74880 bits per second. Then it is switched to 9600 rate as instructed by the following command:

```cpp
Serial.begin(9600) 
```

In there are issues with DHT sensor connections or configuration you will see a repetitive error message “Failed to read from DHT sensor!” displayed on the Serial Monitor. 

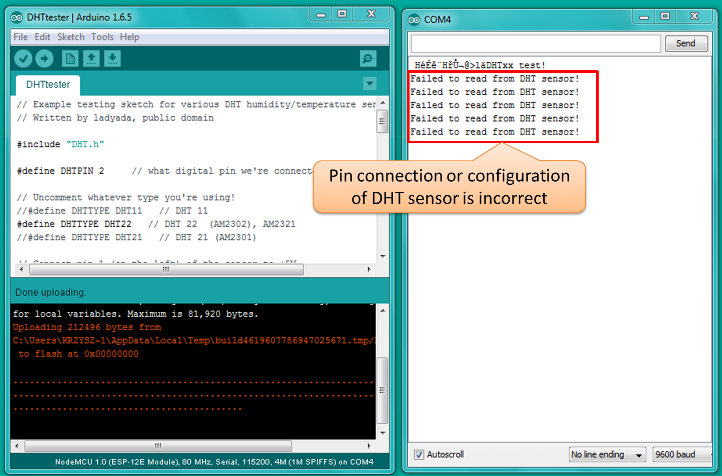
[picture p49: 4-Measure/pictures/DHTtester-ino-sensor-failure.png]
Serial Monitor output - Failed to read from DHT sensor!


If this is the case then verify DHT sensor connections and configuration:

* Are all three sensor pins correctly connected?
* Is 3.3V power supply provided to the sensor?
* Is ``` DHTPIN ``` set up correctly?
* Is ``` DHTTYPE ``` set up correctly?

Please see below the hardware setup used for preparation of this tutorial.

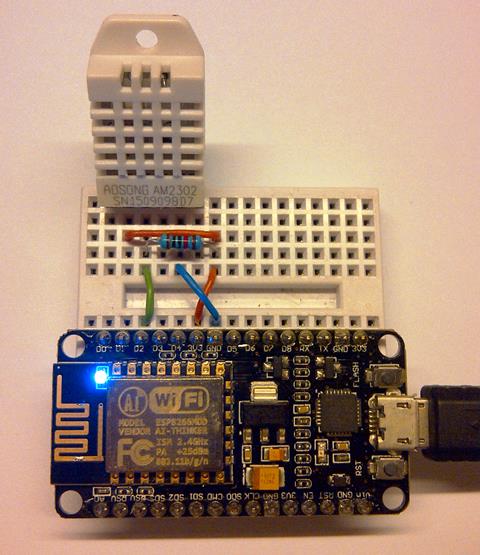
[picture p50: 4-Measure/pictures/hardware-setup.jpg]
DHT Sensor and ESP module on breadboard


## Next Step

Now you know to use ESP8266 to measure humidity. With no effort at all, using the same DHT sensor you can also measure temperature. In section [Show](../5-Show) I will describe how to display current measurements on-line in a web browser.

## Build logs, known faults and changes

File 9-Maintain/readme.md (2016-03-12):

# Maintain

## Table of Contents

* [Introduction](#introduction)
* [Preparation](#preparation)
* [Update the Sketch](#update-the-sketch)
* [Make First Upload](#make-first-upload)
* [Make Next Uploads Faster](#make-next-uploads-faster)
* [Conclusion](#conclusion)

## Introduction

In [previous section](../8-Automate) we have completed our goal of implementation of automatic humidity control. Now I would like to discuss supplementary topic of making the changes to the sketch in more convenient way. For sure you have several ides how to improve this project by providing better automatic control strategy, more friendly and feature rich user interface or maybe adding additional sensors to monitor conditions in your house.

If you have been working with Arduino UNO board before, you may noticed that compilation and then uploading a sketch to ESP8266 takes a lot of time. This is due to size of compiled sketch that is likely 10x bigger comparing to Arduino UNO. To upload [OnlinHumidifier-Automate.ino](../8-Automate/OnlineHumidifier-Automate) sketch using a serial port takes about 30 seconds. Fortunately we can improve this time if we upload module using Wi-Fi connection rather than a serial port. Such method of module upload is called OTA (Over the Air) and has some additional benefits. You can get rid of USB/serial cable and can perform the update remotely - there is no limitation how far the module is located assuming that it is reachable over Wi-Fi connection.

There are three basic options to perform OTA uploads and they are discussed in in details in [documentation](https://github.com/esp8266/Arduino/blob/master/doc/ota_updates/readme.md#introduction) of [esp8266/Arduino] (https://github.com/esp8266/Arduino) repository. Out of these options I would like to implement uploads directly from [Arduino IDE] (https://github.com/esp8266/Arduino/blob/master/doc/ota_updates/readme.md#arduino-ide).

## Preparation

To start with please check documentation what are the [basic requirements](https://github.com/esp8266/Arduino/blob/master/doc/ota_updates/readme.md#basic-requirements) for performing OTA. If the module you are using meets these requirements then go to the next step. 

To perform OTA using Arduino IDE you need Arduino IDE **1.6.7** and **2.0.0** or newer version of ESP8266 platform package. Please update your software if you have earlier versions following instructions in chapter [Installing with Boards Manager](https://github.com/esp8266/Arduino#installing-with-boards-manager) under https://github.com/esp8266/Arduino.

Now go to [esp8266/Arduino] (https://github.com/esp8266/Arduino) repository, open [documentation](https://github.com/esp8266/Arduino/blob/master/doc/ota_updates/readme.md#arduino-ide) and follow detailed step by step instructions to practice OTA updates. During this practice you will use *BasicOTA.ino* sketch available in Arduino IDE under *File > Examples > ArduinoOTA*.

Finally open your sketch [OnlinHumidifier-Automate.ino](../8-Automate/OnlineHumidifier-Automate) and save it as *OnlinHumidifier-Maintain.ino*. Then open *BasicOTA.ino* sketch as well. We will use it as an example of OTA implementation and copy from it the OTA code to our new *OnlinHumidifier-Maintain.ino* sketch.

## Update the Sketch

After reading documentation and following example with *BasicOTA.ino* you should have basic idea how OTA works. More details are provided below.

First copy to you sketch two header file  includes required for ArduinoOTA implementation. In original *BasicOTA.ino* file there are more includes, but we have some of them in our sketch already.

```cpp
#include <WiFiUdp.h>
#include <ArduinoOTA.h>
```

Then define actions to be performed on start and end of OTA update as well as on particular errors. This should be done in ``` setup() ```, as in original example:

```cpp
  ArduinoOTA.onStart([]() {
    Serial.println("OTA upload start");
    // switch humidifier off in case OTA fails
    actionTransmitter.sendSignal(1, 'A', LOW);
    Serial.println("Humidifier switched off");
  });
  
  ArduinoOTA.onEnd([]() {
    Serial.println("OTA upload end");
  });
  
  ArduinoOTA.onError([](ota_error_t error) {
    Serial.printf("Error[%u]: ", error);
    if (error == OTA_AUTH_ERROR) Serial.println("Auth Failed");
    else if (error == OTA_BEGIN_ERROR) Serial.println("Begin Failed");
    else if (error == OTA_CONNECT_ERROR) Serial.println("Connect Failed");
    else if (error == OTA_RECEIVE_ERROR) Serial.println("Receive Failed");
    else if (error == OTA_END_ERROR) Serial.println("End Failed");
  });
```
Note that on OTA start ``` ArduinoOTA.onStart([]() ``` we are switching the humidifier off ``` actionTransmitter.sendSignal(1, 'A', LOW) ```. Imagine what may happen if humidifier is on during OTA and the OTA process fails. Humidifier will keep going until we fix the code or switch it off manually. This normally should not be a problem unless OTA update is done from remote location and we have no physical access to switch it off. Therefore it is a good practice to bring the equipment controlled by module to safe state before attempting to flash a new code.

If you are planning to set up a network of several ESP modules, consider giving each of them an easy to recognize name. This name will be then visible in Arduino IDE, so you have easier time selecting particular module for upload. To do so use ``` ArduinoOTA.setHostname(TheHostNmae) ``` and place this code in ``` setup() ``` as well:

```cpp
  ArduinoOTA.setHostname("OTA-Humidifier");
```

As the final preparation step announce that module is available to OTA. This will start mDNS service using provided above hostname.

```cpp
  ArduinoOTA.begin();
```

Now all you need to do is to instuct module at which condition to accept OTA packets. This is done using ``` ArduinoOTA.handle() ``` function call. To have better conrol when update is done, in you final application consider allowing OTA only on certain condition, e.g. when "OTA Update" button is pressed. In this particular case our goal is to speed up module uploads. Therefore we would like the module to be available for OTA anytime it joins Wi-Fi network. To do so we will simply place this function call in a ``` loop() ```:

```cpp
loop()
{
  ArduinoOTA.handle();

 (...)
 
}
```
Note that in original sketch [OnlinHumidifier-Automate.ino](../8-Automate/OnlineHumidifier-Automate) the code in ``` loop() ``` runs continuously not being blocked by functions like  ``` delay(10000) ```. This way the module is ready to proceed with update immediately after OTA process is started from Arduino IDE. 

## Make First Upload

Before being able to update sketch using OTA you need to upload module for the first time using traditional serial port. Therefore upload module as you were doing it before without changing any upload settings.

Do not worry if during compilation you will see errors like below:

```
(...)In function 'void loop()':

OnlineHumidifier-Maintain:201: error: 'measureHumidity' was not declared in this scope
     measureHumidity();
                     ^
OnlineHumidifier-Maintain:204: error: 'executeHumidityControl' was not declared in this scope
       executeHumidityControl();
                              ^
OnlineHumidifier-Maintain:206: error: 'sendDataToEmoncms' was not declared in this scope
     sendDataToEmoncms();
                       ^
exit status 1
'measureHumidity' was not declared in this scope
```

This is due to issue [#1066](https://github.com/esp8266/Arduino/issues/1066). You need to add all missing function prototypes if particular function is not declared before it is called for the first time. In our case, according to error log above, thre are three functions like that:

```cpp
void measureHumidity(void);
void executeHumidityControl(void);
void sendDataToEmoncms(void);
```

Add them in declaraction section in file *OnlinHumidifier-Maintain.ino*. For complete code, including missing prototypes as well as OTA routines, please refer to [OnlinHumidifier-Maintain.ino](OnlineHumidifier-Maintain).

Now upload updated sketch (Ctrl+U), check how long it takes, and get ready to do upload faster with OTA!

## Make Next Uploads Faster

For you next uploads, all you need to do is to select OTA port, that should show up as below. 

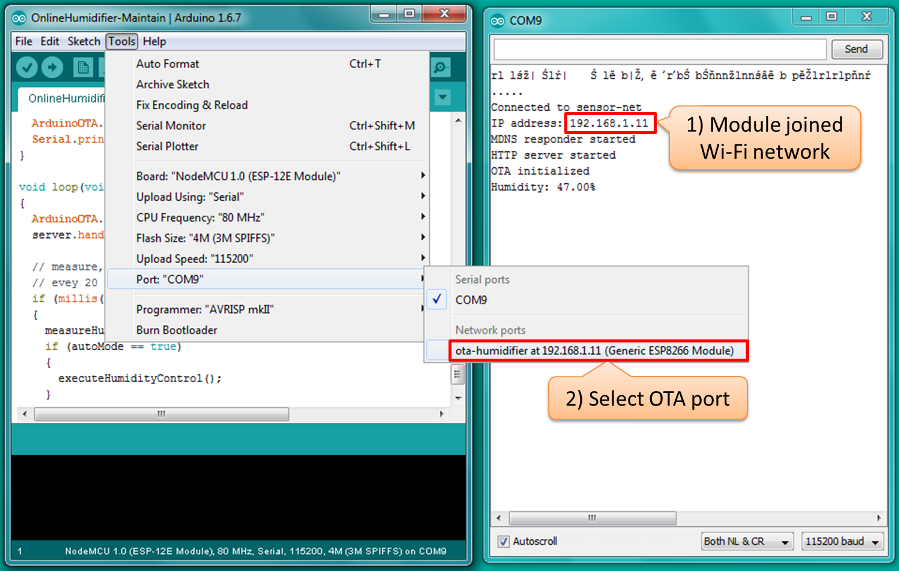
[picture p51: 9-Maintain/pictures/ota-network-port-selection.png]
OTA port selection in Arduino IDE


Select OTA port, click upload button (Ctrl+U) and measure upload time again. For me it took 10 seconds. Congratulations! You have improved upload period three times (300%) :smile:

Please see below how OTA process looks like on [external serial terminal](https://github.com/esp8266/Arduino/blob/master/doc/ota_updates/readme.md#troubleshooting). 

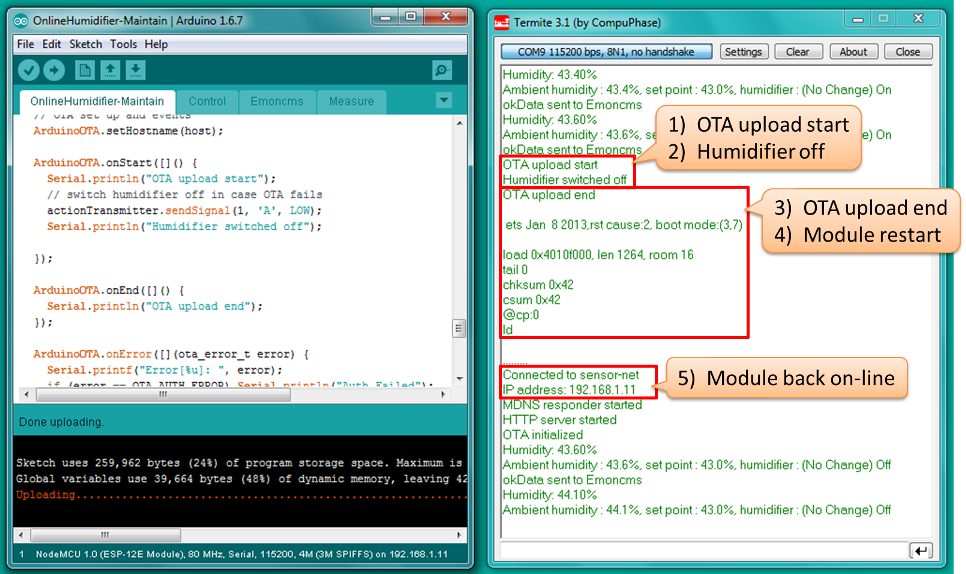
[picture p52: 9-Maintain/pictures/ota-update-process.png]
OTA update process monitoring in external serial terminal


## Conclusion

This concludes the last section of project [how to automatically control humidity in your home](https://github.com/krzychb/OnlineHumidifier). I hope you like it :smile: 

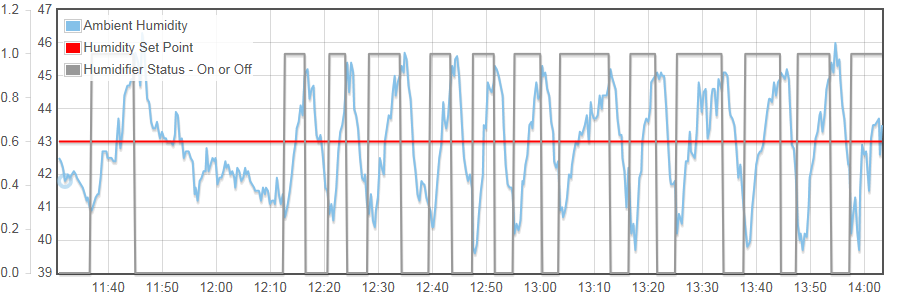
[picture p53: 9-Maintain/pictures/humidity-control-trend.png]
Sample trend of humidity control


If you find any issues with code or descriptions, please report them using *Issues* tab above. If you have any suggestions, post them in [this thread](http://www.esp8266.com/viewtopic.php?p=37446#p37446) of [ESP8266 Community Forum](http://www.esp8266.com/). 

There are many ways you can improve this project to better suit you needs. Explore some of them in [next section](../A1-MQTT).

Krzysztof

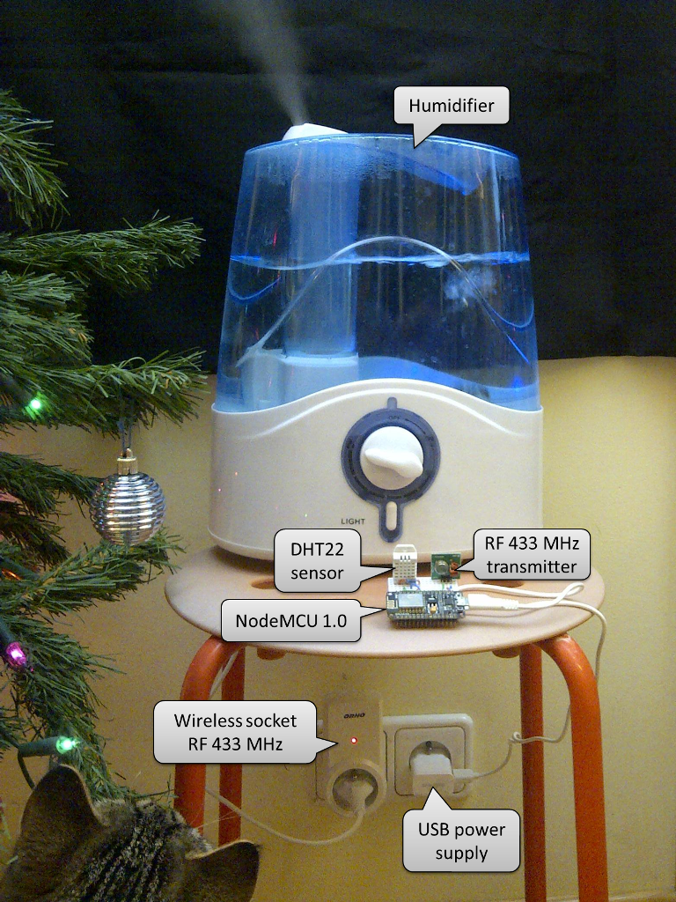
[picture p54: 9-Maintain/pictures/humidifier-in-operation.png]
Humidifier in operation in my room


P.S. Actually the humidity sensor should be placed away from humidifier. Otherwise desired humidity level may be maintained only in the local area nearby. I put everything close together to show all required components on one picture.

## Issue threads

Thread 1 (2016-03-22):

Compiling of OnlineHumidifier-openHAB.ino gives error

semaf, 2016-03-22:
Hey,

There are missing some libraries and compiling has problems. Would you fix that?

cheers

krzychb, 2016-03-22:
Hi semaf,

Thank you for issuing first report on this repository :smile:

Please post the compilation log so I can check where the problem is.
What version of ESP8266 core you are using?
What is your version of Arduino IDE?

Krzysztof

semaf, 2016-03-22:
Nice that I am for a second time to first ;)

Well there are a lot of Errors due the DHT, RF433, Emoncms etc.. I would say you should make a clean Sketch without additions of RF433 or anything else.. Just DHT22 + ESP8266 + OPENHAB + MQTT and that would be clean enough.

Errors:
**#1 just compiled:**
```
OnlineHumidifier-openHAB:31: error: 'D2' was not declared in this scope
OnlineHumidifier-openHAB:44: error: 'D1' was not declared in this scope
OnlineHumidifier-openHAB.ino:45:37: note: in expansion of macro 'RF433_TR_PIN'
'D2' was not declared in this scope
```

#2 corrected Pins to 2 and 14 instead D2 and D14:
```
OnlineHumidifier-openHAB.cpp.o: In function `MQTTkeepAlive()':
C:\Program Files (x86)\Arduino/OnlineHumidifier-openHAB.ino:142: undefined reference to `setupWiFi()'
C:\Program Files (x86)\Arduino/OnlineHumidifier-openHAB.ino:142: undefined reference to `setupWebserver()'
C:\Program Files (x86)\Arduino/OnlineHumidifier-openHAB.ino:142: undefined reference to `setupOTA()'
OnlineHumidifier-openHAB.cpp.o: In function `MQTTpublishData()':
C:\Program Files (x86)\Arduino/OnlineHumidifier-openHAB.ino:143: undefined reference to `setupWiFi()'
OnlineHumidifier-openHAB.cpp.o: In function `HardwareSerial::begin(unsigned long)':
C:\Program Files (x86)\Arduino/OnlineHumidifier-openHAB.ino:143: undefined reference to `setupWebserver()'
C:\Program Files (x86)\Arduino/OnlineHumidifier-openHAB.ino:143: undefined reference to `setupOTA()'
OnlineHumidifier-openHAB.cpp.o: In function `swap<void (*)(const std::_Any_data&, const MQTT::Publish&)>':
c:\users\michi\appdata\roaming\arduino15\packages\esp8266\tools\xtensa-lx106-elf-gcc\1.20.0-26-gb404fb9-2\xtensa-lx106-elf\include\c++\4.8.2\bits/move.h:177: undefined reference to `measureHumidity()'
OnlineHumidifier-openHAB.cpp.o: In function `swap<std::_Any_data>':
c:\users\michi\appdata\roaming\arduino15\packages\esp8266\tools\xtensa-lx106-elf-gcc\1.20.0-26-gb404fb9-2\xtensa-lx106-elf\include\c++\4.8.2\bits/move.h:176: undefined reference to `executeHumidityControl()'
OnlineHumidifier-openHAB.cpp.o: In function `swap<void (*)(const std::_Any_data&, const MQTT::Publish&)>':
c:\users\michi\appdata\roaming\arduino15\packages\esp8266\tools\xtensa-lx106-elf-gcc\1.20.0-26-gb404fb9-2\xtensa-lx106-elf\include\c++\4.8.2\bits/move.h:176: undefined reference to `sendDataToEmoncms()'
OnlineHumidifier-openHAB.cpp.o: In function `loop':
C:\Program Files (x86)\Arduino/OnlineHumidifier-openHAB.ino:186: undefined reference to `measureHumidity()'
C:\Program Files (x86)\Arduino/OnlineHumidifier-openHAB.ino:188: undefined reference to `executeHumidityControl()'
C:\Program Files (x86)\Arduino/OnlineHumidifier-openHAB.ino:191: undefined reference to `sendDataToEmoncms()'
collect2.exe: error: ld returned 1 exit status
Error compiling.
```

Thats why a clean version would be great :)

krzychb, 2016-03-22:
I see your point and thank you for taking time to document it. This is a good opportunity to expand this repository with another section (Just DHT22 + ESP8266 + OPENHAB + MQTT).

- Removing Emoncms is easy to justify. Charts may be done directly in openHAB.
- What about RF433? I need to provide some reasonable way to automatically turn humidifier on and off for closed loop control. What would you provide instead?

Krzysztof

semaf, 2016-03-22:
A delay is also fine. Mostly Humdity and Temperature Sensors are never going to be turned off but adding a delay would be enough.

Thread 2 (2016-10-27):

errors reading sensor

consolacion, 2016-10-27:
First: great article, but I came across something odd.
I have come as far as using the Onlinehumidiefier-MQTT, however, the  DHT11 sensor is read correct  one time after startup and subsequently it will not read (returning the error message). I have temporarily  blocked out the 'return' to get it out of endless trying and to see whats happening but it will just have a read error most of the time with a  very sporadic  correct read.
I did set the type correct but even if I would not have, I would still see a reading albeit not correct, but as said I just dont get a reading at all.
if I do a reset, yes then the first or second reading will succeed but then it is just 'failed to read' most of the time.

Ofcourse I tried a different sensor, same results. So I tried just reading the sensor with a basic program as provided in the library, works perfect. So, although I do not have a clou yet how, but somehow the entire program is interfering with the reading of the sensor.
If I add a float variable "t" to read the temperature, that has the same problems: sensor just  likes to be read directly after startup and further no more, while  the library example program works flawlessly.

I tried  shortening the 20 sec interval to no avail.

Obviously something is not ok here. Any ideas? Using a Wemos D1 mini

But again, great article

consolacion, 2016-10-27:
The error seems to be introduced after the nr 7 'Control Sketch' that one   reads  the Sensor  time after time and comes back with a normal value, where asnr 8 'Automate' only reads incidental (like immediately after startup)   and subsequently  returns "Failed to read" errors. So obviously something in the automate sketch was introduced that fauls up the sensor read, but I have no idea what

krzychb, 2016-10-27:
Hi @consolacion,

I have also noticed DHT sensor read errors but for DHT22 I was using.
The error has been resolved after implementing [this fix](https://github.com/adafruit/DHT-sensor-library/issues/48) that to DHT11.

Please check it out - I wonder if this fix will work for you as well.

consolacion, 2016-10-27:
Thanks, I will give that a try and get back to you. In the mean time I found that pushing two time critical routines in the .cpp file greatly improved the situation http://www.esp8266.com/viewtopic.php?f=32&t=4210&start=28

consolacion, 2016-10-27:
Yes, that seems to have done the rick as well. Thanks a bundle and a again... great series of articles.  Didnt get the OTA working yet (no OTA port appearing)  but I'll sort that out when I have  need for it :-)
You helped me  really a lot with this article series, learned a lot

krzychb, 2016-10-28:
Thank you for update and good news that the issue is resolved :+1:
I am really happy you found this repository helpful :smile:

Closed 2016-10-28.

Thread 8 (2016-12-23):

Temperature problem

xxvms, 2016-12-23:
Hi Krzychb

first of all Merry Christmas :)
i have followed your tutorial thanks for that.
However I am struggling to get Humidity and temperature together.
so what I have done is in sketch
If I have this line
`   getJSON += "/input/post.json?json={Temperature:" + (String) temperature + "}";
and of course same goes for Humidity it works fine.

I am able to get temperature readings, however when I try to combine both Temperature and Humidity
I am not getting anywhere.
my line of code is as follows:

      `getJSON += "/input/post.json?json={Humidity:" + (String) humidity +", Temperature:" + (String) temperature +"}";
`
and message I got from console is
Data sent to Emoncms
Humidity: 45.40
Temperature: 22.60

so I should be able to see 2 feeds one for Humidity and one for temperature, but I don't.
Can you suggest what I am doing wrong?

thanks :)
`

krzychb, 2016-12-23:
Hi @xxvms,

Merry Christmas!

The line you are showing looks correct to me. What about the rest of the query string? Sending more variables is shown in next sections, for instance in [8-Automate](https://github.com/krzychb/OnlineHumidifier/tree/master/8-Automate#lets-get-it-work).

The part of code printing confirmation to the console is very simple. It is not actively waiting for reply from Emoncms. This creates a problem that you are likely to miss error message, if query sting is incorrect and response slow,

Check my other repository [EspToCloud](https://github.com/krzychb/EspToCloud) that contains slightly more advanced version of this code that is waiting for response from server. It also contains [program flow diagram](https://github.com/krzychb/EspToCloud#functionality) explaining how it works.

If you use this code instead, you should be able to see confirmation from Emoncms if the data have been correctly received.

Krzysztof

xxvms, 2016-12-23:
Hi Krzychb

thanks for that, I overcome the issue by creating new function in the sketch, not sure if  there was better way, but this one worked. I will check your suggestion as for some reason I didn't get to see that.

```
void sendDataToEmoncmsHumidity(void)
{
  if (client.connect(emoncmsServer, 80))
  {
    String getJSON = "";
    getJSON += "GET http://" + (String) emoncmsServer;
    getJSON += "/input/post.json?json={Humidity:" + (String) humidity +"}";
    getJSON += "&apikey=" + apiKeyEmoncms + "\n";
    getJSON += "Connection: close\n\n";
    client.print(getJSON);
    // display response from Emoncms
    while (client.available())
    {
      Serial.write(client.read());
    }
    Serial.println("Data sent to Emoncms");
  }
  else
  {
    Serial.println("Connection to Emoncms failed");
  }
  client.stop();
}

void sendDataToEmoncmsTemp(void)
{
  if (client.connect(emoncmsServer, 80))
  {
    String getJSON = "";
    getJSON += "GET http://" + (String) emoncmsServer;
    getJSON += "/input/post.json?json={Temperature:" + (String) temperature + "}";
    getJSON += "&apikey=" + apiKeyEmoncms + "\n";
    getJSON += "Connection: close\n\n";
    client.print(getJSON);
    // display response from Emoncms
    while (client.available())
    {
      Serial.write(client.read());
    }
    Serial.println("Data sent to Emoncms");
  }
  else
  {
    Serial.println("Connection to Emoncms failed");
  }
  client.stop();
}

```

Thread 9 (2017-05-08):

strings vs numbers

consolacion, 2017-05-08:
Not really an issue, but more curiosity from my part: You send the humidity as  a string with "(String) humidity", however in OpenHab item file you consider it as a number, even as a float with
"Number Humidity			"Ambient Humidity [%.0f %%]"	<water>		{mqtt="<[test:krzychb/home/sensor/Humidity:state:default]"}"
Now obviously that works as I have tried myself, but on other occasions I found openhab rather picky on using a via MQTT received string payload as a number.
Am I missing something ?

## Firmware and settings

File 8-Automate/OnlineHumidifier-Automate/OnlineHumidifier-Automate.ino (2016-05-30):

// This is example file from https://github.com/esp8266/Arduino
// It has been modified for the purpose of OnlineHumidifier project - https://github.com/krzychb/OnlineHumidifier


//
// DHT Sensor Setup
//
#include "DHT.h"
//  dht(DHTPIN, DHTTYPE);
DHT dht(D2, DHT22);
float humidity;
float humiditySetPoint = 43;


//
// RF 433 transmitter configuration
//
// download - https://bitbucket.org/fuzzillogic/433mhzforarduino/wiki/Home/
//
#include <RemoteTransmitter.h>
#define RF433_TR_PIN D1   // pin where RF433 Transmitter is connected to
ActionTransmitter actionTransmitter(RF433_TR_PIN);
bool humidifier = LOW;
bool autoMode = false;

//
// Wi-Fi Setup
//
#include <ESP8266WiFi.h>
#include <WiFiClient.h>
#include <ESP8266WebServer.h>
#include <ESP8266mDNS.h>

const char* ssid = "********";     // your network SSID (name)
const char* password = "********";  // your network password

ESP8266WebServer server(80);


//
// Emoncms configuration
//
// Domain name of emoncms server - "emoncms.org"
// If unable to connect with domant name, use IP adress instead - "80.243.190.58"
const char* emoncmsServer = "emoncms.org";
//                       enter your Read & Write API Key below 
String apiKeyEmoncms = "9a3e3c9cf65c70a597097b065dcb24e3";
WiFiClient client;


void handleRoot() {
  String message = "hello from esp8266!";
  message += "\nHumidity = ";
  message += (String) humidity;
  message += "%";

  server.send(200, "text/plain", message);
}

void handleNotFound() {
  String message = "File Not Found\n\n";
  message += "URI: ";
  message += server.uri();
  message += "\nMethod: ";
  message += (server.method() == HTTP_GET) ? "GET" : "POST";
  message += "\nArguments: ";
  message += server.args();
  message += "\n";
  for (uint8_t i = 0; i < server.args(); i++) {
    message += " " + server.argName(i) + ": " + server.arg(i) + "\n";
  }
  server.send(404, "text/plain", message);
}

void showControlScreen(void) {
  String message;
  message += "<html>";
  message += "<head><meta http-equiv='refresh' content='20'/><title>Online Humidifier</title></head>";
  message += "<body>";
  message += "<h3>Humidifier Control - ";
  message += (String) (autoMode == true ? "Auto" : "Manual");
  message += "</h3>";
  message += "<p>";
  message += "Humidity : " + (String) humidity + "%<br />";
  message += "Humidifier : " + (String) humidifier + "<br />";
  message += "Operate : ";
  message += "<a href=\"/humidifier/1\">On</a>";
  message += " / ";
  message += "<a href=\"/humidifier/0\">Off</a>";
  message += " / ";
  message += "<a href=\"/humidifier/Auto\">Auto</a>";
  message += "</body>";
  message += "</html>";

  server.send(200, "text/html", message);
}


void setup(void) {
  Serial.begin(115200);

  dht.begin();
  WiFi.begin(ssid, password);
  Serial.println();

  // Wait for connection
  while (WiFi.status() != WL_CONNECTED) {
    delay(500);
    Serial.print(".");
  }
  Serial.println();
  Serial.print("Connected to ");
  Serial.println(ssid);
  Serial.print("IP address: ");
  Serial.println(WiFi.localIP());

  if (MDNS.begin("esp8266")) {
    Serial.println("MDNS responder started");
  }

  server.on("/", handleRoot);

  server.on("/humidifier/1", []() {
    autoMode = false;
    humidifier = HIGH;
    actionTransmitter.sendSignal(1, 'A', humidifier);
    showControlScreen();
  });

  server.on("/humidifier/0", []() {
    autoMode = false;
    humidifier = LOW;
    actionTransmitter.sendSignal(1, 'A', humidifier);
    showControlScreen();
  });

  server.on("/humidifier/Auto", []() {
    autoMode = true;
    showControlScreen();
  });

  server.onNotFound(handleNotFound);

  server.begin();
  Serial.println("HTTP server started");
}

void loop(void)
{
  server.handleClient();

  // measure, control and send to Emoncms.org
  // evey 20 seconds
  if (millis() % 20000 == 0)
  {
    measureHumidity();
    if (autoMode == true)
    {
      executeHumidityControl();
    }
    sendDataToEmoncms();
  }
}

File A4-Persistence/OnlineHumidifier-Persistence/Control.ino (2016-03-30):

/*
  Control of Humidifier Connected to a RC Socket
  https://github.com/krzychb/OnlineHumidifier
  Part A4 - Persistence

  Copyright (c) 2015 Krzysztof Budzynski. All rights reserved.
  This file is part of OnlineHumidifier project - https://github.com/krzychb/OnlineHumidifier

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
  You should have received a copy of the GNU Lesser General Public
  License along with this library; if not, write to the Free Software
  Foundation, Inc., 51 Franklin St, Fifth Floor, Boston, MA  02110-1301  USA
*/


//
// Humidifyer Control
//
// Switch humidifyer On if measured humidity is below set point
// Switch it off if it is above the set point
// Add hysteresis of 2 % RH above and below the set point
// so RC socket and humidifyer are not abused by frequent switching
//
void executeHumidityControl(void)
{
  Serial.print("CONTROL > Humidity: ");
  Serial.print(humidity, 1);
  Serial.print("%, SetPoint: ");
  Serial.print(humiditySetPoint, 1);
  Serial.print("%, Humidifier: ");
  if (humidity > humiditySetPoint + 2)
  {
    // ambient humidity is above the set point
    // action : switch humidifyer Off
    humidifier = LOW;
  }
  else if (humidity < humiditySetPoint - 2)
  {
    // ambient humidity is below the set point
    // action : switch humidifyer On
    humidifier = HIGH;
  }
  else
  {
    // ambient humidity is within +/- 2% hysteresis
    // therefore do not alter curent status of humidifyer
    Serial.print("(No Change) ");
  }
  Serial.println(humidifier == HIGH ? "On" : "Off");

  //
  // Set first two parameters below to match your RC socket
  //
  // systemCode : 0..31
  // device : A..E
  //
  // Use third parameter to put the RC socket On or Off
  //
  // state : HIGH / LOW
  //
  actionTransmitter.sendSignal(1, rcDevice, humidifier);

}

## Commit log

2016-01-31 Initial release - topics 1..9
    Appendix published - topics A1..A2
    Topic A3 published: HTTP - A binding alternative to MQTT?
    [esp8266-dht22-rf433.fzz, esp8266-dht22.fzz, openhab.cfg]
2016-03-12 Specified Arduino IDE version to use
2016-03-12 Updated sendDataToEmoncms and meta 'refresh'
    * so get string commands are not send on every web page refresh
    * Missing infor about function prototype
    * Highlighted information about s/w versions required
    [Emoncms.ino, OnlineHumidifier-Automate.ino, OnlineHumidifier-Chart.ino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]
2016-11-17 Included note about quotes in JSON standard
    This is follow up on comments to https://arduinodiy.wordpress.com/2016/10/30/esp8266-with-webserver-mqtt-emoncms-thingspeak-ota/#comments
